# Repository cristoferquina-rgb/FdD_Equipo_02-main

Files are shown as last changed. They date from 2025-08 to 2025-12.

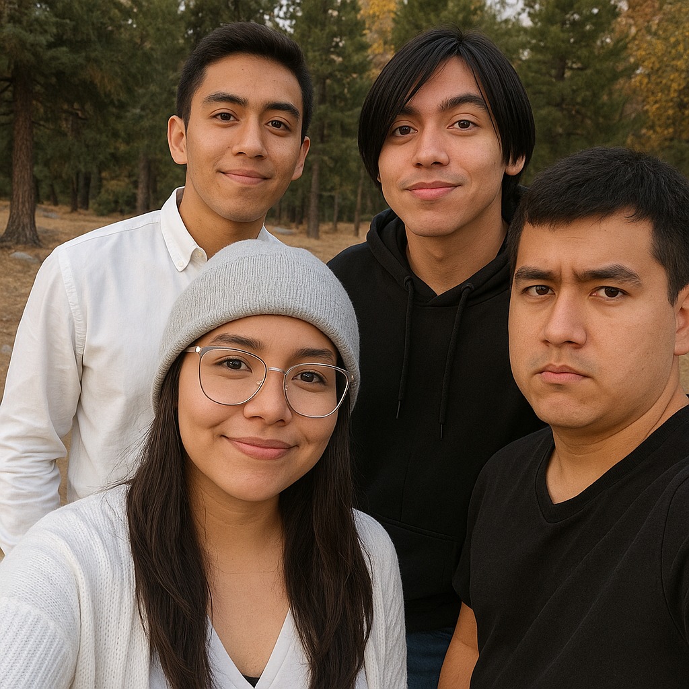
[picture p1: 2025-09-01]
Recursos/Imágenes/equipo.png

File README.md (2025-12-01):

# Equipo 02 - Fundamentos de Diseño 2025-2  
### Carrera de Ingeniería Informática / Industrial  
**Universidad Peruana Cayetano Heredia**



## 📑 Índice

1. [📘 Presentación del Equipo](#presentación-del-equipo)
2. [⭐ ODS Prioritario](#ods-prioritario)
3. [📸 Fotografía del Equipo](#fotografía-del-equipo)
4. [👥 Integrantes del Equipo](#integrantes-del-equipo)
5. [📝 Problemática en el Perú](#problemática-en-el-perú)
6. [💡 Propuesta de Solución – SmartVent](#propuesta-de-solución--smartvent)
7. [⚙️ Funciones del Sistema](#funciones-del-sistema)
8. [📦 Módulos del Proyecto](#módulos-del-proyecto)
    - [🔌 Módulo Electrónico](#módulo-electrónico)
    - [🛠️ Módulo Mecánico](#módulo-mecánico)
    - [💻 Módulo de Software](#módulo-de-software)
9. [📋 Componentes Utilizados](#componentes-utilizados)
10. [✨ Conclusiones y Trabajo Futuro](#conclusiones-y-trabajo-futuro)

## 📘 Presentación del Equipo

Somos el Equipo 02 del curso Fundamentos de Diseño 2025-2, conformado por estudiantes comprometidos con el desarrollo de soluciones innovadoras con impacto social, tecnológico y ambiental.

Nuestro trabajo se alinea con los Objetivos de Desarrollo Sostenible (ODS), especialmente los relacionados con ciudades sostenibles y resilientes.

## ⭐ ODS Prioritario

**ODS 11 – Ciudades y comunidades sostenibles**
**ODS 3 – Salud y Bienestar**

Nuestro prototipo se alinea con los ODS 3 (Salud y Bienestar) y ODS 11 (Ciudades Sostenibles), impulsando el bienestar y la sostenibilidad en el hogar. 

## 📸 Fotografía del Equipo  
<p align="center">

 <br>
  <em>Figura 1. Fotografía del equipo 2</em>
</p>

## 👥 Integrantes del Equipo  

| Foto | Nombre | Rol | Intereses |
|---|---|-----|---|
|  | **Idania Channara Parhuay Meza** | Líder del equipo | Innovación social, sostenibilidad |
|  | **Eber Pauccara Huancara** | Diseñador/a | Diseño de prototipos, creatividad aplicada |
|  | **Cristofer Andherson Quina Pumahuillca** | Encargado/a de documentación | Comunicación científica, redacción técnica |
|| **Sebastian Calderon Junes** | Programador/a - Modelador/a | Programación, análisis de datos, simulación |

## 📝Problemática en el Perú

En el Perú, la ventilación en viviendas, oficinas y colegios es ineficiente. Muchos espacios permanecen cerrados durante horas, lo que provoca acumulación de gases, humedad y temperaturas elevadas. Esto afecta la salud, la seguridad y el confort de los habitantes.

Además, los incendios urbanos representan un riesgo creciente. La inhalación de humo y gases tóxicos es una de las principales causas de muertes en siniestros domésticos. Muchas ventanas no cuentan con mecanismos de apertura rápida ni sistemas inteligentes que respondan automáticamente ante fugas de gas o humo.

Esta realidad evidencia la necesidad de un sistema retrofit, compacto, adaptable y seguro, capaz de mejorar la ventilación, detectar peligros y actuar sin intervención humana.

<p align="center">


## Propuesta de Solución – SmartVent

SmartVent es un módulo retrofit inteligente que integra sensores ambientales, un mecanismo motorizado de apertura y un sistema de comunicación para emergencias.
Permite ventilar de forma automática ante niveles peligrosos de gas o temperatura.

El sistema analiza continuamente el ambiente interior y responde mediante apertura, activación de alarmas y envío de alertas remotas. Su diseño es compacto, adaptable a marcos existentes y pensado para funcionar sin interrumpir la vida cotidiana.

<p align="center">


## Funciones del Sistema

🔹Función principal

- Integrar sensores de gases, temperatura y humedad en una ventana retrofit.
- Detectar fugas, cambios bruscos de temperatura y niveles críticos que comprometan la salud.
- Accionar automáticamente el mecanismo de apertura para ventilar.

🔹 Funciones secundarias

- Enviar alertas locales y remotas.
- Reconocer la calidad del aire y abrirse automáticamente si está contaminado.
- Activar apertura en situaciones de emergencia.

🔹 Funciones de control

- Procesar información en tiempo real con retroalimentación inmediata al usuario.

🔹 Funciones mecánicas

- Lograr movimiento estable mediante engranaje móvil.
- Permitir aperturas graduales.

🔹 Funciones de seguridad

- Detectar humo, gases y partículas tóxicas.
- Permitir apertura manual en caso necesario.

## Módulos del Proyecto

### 🔌Módulo Electrónico

- Incluye sensores de gases, temperatura, humedad y partículas.
- Cuenta con señales de entrada como: encendido, inicio, parada y lecturas de sensores.
- Cuenta con señales de salida como: estado, emergencia, fin de proceso y control de actuadores.
- Funciona conectado a la red eléctrica.
- El hardware incluye mecanismos que abren la ventana.

<p align="center">


### 🛠️Módulo Mecánico

- El módulo es compacto y adaptable a marcos existentes.
- Su cinemática garantiza un movimiento estable del engranaje y del sistema de apertura.
- El motor debe superar peso, fricción y presión del viento, con margen de seguridad.
- La estructura está diseñada según normas de seguridad contra incendios y calidad del aire.
- Incluye mecanismo de desbloqueo manual para emergencias.
- Está construido para cumplir criterios de ergonomía: suave, silencioso y fácil de usar para cualquier persona.
  
<p align="center">


### 💻Módulo de Software

- Controla sensores, alarmas, extractor y actuadores según el algoritmo.
- Ofrece una aplicación móvil con alertas e historial de calidad del aire.
- Cuenta con dashboard en tiempo real.
- El firmware administra adquisición de datos y control del actuador.
- Gestiona los modos de operación del sistema.

<p align="center">


## 📋Componentes Utilizados

A continuación se presenta un cuadro organizado para completar los componentes empleados en el proyecto, clasificados según su función dentro del sistema.

### 🔌Componentes Electrónicos

| Componente | Cantidad | Función | Exigencia Asociada |
|---|---|---|---|
| Sensor de gas (MQ-x) |1 | Detecta fugas de GLP y gases inflamables | Detectar fugas de gases dentro del ambiente |
| Sensor de temperatura y humedad (DHT/HTU21D) | 1 | Mide condiciones internas del ambiente | Propiedades físicas y químicas: temperatura y humedad |
| Microcontrolador (ESP32)| 1 | Procesamiento, control y comunicación | Centro del sistema: programa autónomo |
| Motor DC 12V 300 RPM | 1 | Acciona la apertura/cierre del sistema mecánico | Superar peso, fricción y presión del viento |
| Driver de motor | 1 | Control del motor mediante el microcontrolador | Control de salidas y actuadores |
| Fuente 12V / regulador | 1 | Alimentación del sistema con protecciones | Alimentación segura y estable |
| Alarma sonora (buzzer) | 1 | Aviso local de emergencias | Señales de emergencia |
| Indicador LED | 1 | Estado del sistema y alertas visuales | Señales luminosas del proceso |

---

### 🛠️Componentes Mecánicos

| Componente | Cantidad | Función | Exigencia Asociada |
|---|---|---|---|
| Engranaje principal | 1 | Transmitir movimiento al sistema de apertura | Cinemática estable del engranaje |
| Barra móvil / brazo mecánico | 1 | Efectuar el movimiento de apertura | Transmisión directa del motor |
| Estructura de soporte | 1 | Montaje seguro sobre la ventana | Instalación rápida y segura |
| Soportes y anclajes | 3 | Estabilidad del módulo | Robustez y resistencia |

---

### 💻Componentes de Software

| Elemento | Función | Exigencia Asociada |
|---|---|---|
| Firmware del microcontrolador | Control de sensores, motor y lógica | Gestión del proceso en tres modos |
| Aplicación móvil / Dashboard | Alertas, datos en tiempo real e historial | Comunicación con el usuario |
| Protocolo IoT (WiFi/Bluetooth) | Envío de notificaciones y monitoreo | Comunicación remota del sistema |

---

## ✨Conclusiones y Trabajo Futuro

SmartVent cumple todas las exigencias técnicas: control, seguridad, ergonomía, energía, señales, mecánica, software e instalación.

El sistema es seguro, silencioso, resistente y accesible.

La modularidad permite mantenimiento sencillo y reemplazo de piezas.

Futuras mejoras pueden incluir:

- Panel solar integrado,

- Más sensores,

- Integración con domótica,

- Versión industrial.

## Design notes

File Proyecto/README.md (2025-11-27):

# 📁 Proyectos – Organización General de Módulos

La carpeta Proyectos contiene los tres módulos principales desarrollados durante el proyecto integrador. Cada módulo aborda una parte esencial del sistema: la electrónica, la mecánica y el software.
A continuación se presenta una descripción general de cada uno.

## 🔌 1. Módulo Electrónico

Carpeta: [Proyectos/Modulo_Electronico](https://github.com/cristoferquina-rgb/FdD_Equipo_02-main/tree/main/Proyecto/M%C3%B3duloElectr%C3%B3nico)

Este módulo reúne todo el diseño y desarrollo del sistema electrónico, desde el esquemático hasta la placa PCB final.

Incluye:

● Diseño del circuito en EasyEDA

● Diseño de PCB (enrutado, capas, footprints)

## 🛠️ 2. Módulo Mecánico

Carpeta: [Proyectos/Modulo_Mecánico](https://github.com/cristoferquina-rgb/FdD_Equipo_02-main/tree/main/Proyecto/M%C3%B3duloMec%C3%A1nico)

En este módulo se encuentran todas las piezas y documentos relacionados al diseño físico del sistema.

Incluye:

● Certificados de Onshape

● Modelado 3D completo del ensamblaje

● Archivos .stl listos para impresión 3D

● Piezas como: caja, tapa, engranajes, soportes, correa, etc.

## 💻 3. Módulo de Software

Carpeta: [Proyectos/Modulo_Software](https://github.com/cristoferquina-rgb/FdD_Equipo_02-main/tree/main/Proyecto/M%C3%B3duloSoftware)

Este módulo contiene el código y la lógica del sistema digital que controla el proyecto.

Incluye:

● Programación del microcontrolador (Arduino, ESP32, etc.)

● Funciones de control y automatización

● Lectura de sensores y manejo de actuadores

● Algoritmos, librerías utilizadas y pruebas

● Documentación del flujo del software

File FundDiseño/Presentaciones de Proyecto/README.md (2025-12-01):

# PÓSTER

POSTER FDD

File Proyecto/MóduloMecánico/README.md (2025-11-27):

# 🛠️ Módulo Mecánico – Modelado 3D en Onshape

Esta sección presenta el desarrollo mecánico del proyecto, desde la validación del modelado en Onshape hasta la generación de las piezas finales exportadas en formato .stl listas para imprimir.

--- 

## ✔️ 1. Certificados de Onshape

Antes de iniciar el modelado, se completaron los módulos obligatorios de capacitación en Onshape, garantizando el uso correcto de herramientas de bocetado, ensamblaje y modelado 3D.

Puedes ver el certificado aquí: [Certificados Onshape](https://github.com/cristoferquina-rgb/FdD_Equipo_02-main/blob/main/Proyecto/M%C3%B3duloMec%C3%A1nico/Certificados%20Onshape.pdf)

## ✔️ 2. Modelado 3D del Sistema

Las piezas del proyecto fueron diseñadas completamente en Onshape, considerando:

● Dimensiones ajustadas al prototipo.

● Ensamblaje funcional entre componentes.

● Compatibilidad con impresión 3D.

● Tolerancias adecuadas para movimiento y acople.

● El modelado incluye: caja, tapa, engranajes, soportes y la correa del mecanismo.

## ✔️ 3. Archivos STL listos para impresión

Los siguientes archivos .stl corresponden a cada una de las piezas diseñadas.
Están listos para ser abiertos en Cura, PrusaSlicer u otro software de impresión 3D.

📦 Piezas del ensamblaje:

● [Caja](https://github.com/cristoferquina-rgb/FdD_Equipo_02-main/blob/main/Proyecto/M%C3%B3duloMec%C3%A1nico/Caja.stl)

● [Tapa]( https://github.com/cristoferquina-rgb/FdD_Equipo_02-main/blob/main/Proyecto/M%C3%B3duloMec%C3%A1nico/tapa.stl)

● [Soporte]( https://github.com/cristoferquina-rgb/FdD_Equipo_02-main/blob/main/Proyecto/M%C3%B3duloMec%C3%A1nico/soporte.stl)

● [Soporte del motor]( https://github.com/cristoferquina-rgb/FdD_Equipo_02-main/blob/main/Proyecto/M%C3%B3duloMec%C3%A1nico/Soporte%20del%20motor.stl)

● [Correa de ventana]( https://github.com/cristoferquina-rgb/FdD_Equipo_02-main/blob/main/Proyecto/M%C3%B3duloMec%C3%A1nico/Correa%20de%20ventana.stl)

● [Engranaje]( https://github.com/cristoferquina-rgb/FdD_Equipo_02-main/blob/main/Proyecto/M%C3%B3duloMec%C3%A1nico/Engranaje.stl)

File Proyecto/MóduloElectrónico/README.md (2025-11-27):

# 🔌 MÓDULO ELECTRÓNICO –  EasyEDA & PCB

Este apartado reúne todo el proceso de diseño electrónico realizado para el proyecto, desde el esquema del circuito hasta la fabricación de la tarjeta PCB.

## ✔️ 1. Diseño del Circuito en EasyEDA

Se desarrolló el esquemático electrónico utilizando EasyEDA, donde se definieron todos los componentes, sus conexiones y la lógica del circuito.
Incluye:

● Selección y colocación de componentes electrónicos.

● Conexión del circuito mediante señales (nets).

● Organización del diagrama con etiquetas y bloques para una lectura clara.

esquema final grupo2_page-0001

---

## ✔️ 2. Diseño del Circuito en EasyEDA (Todos los componentes con fotoprint)
Captura de pantalla 2025-11-24 121837

---

## ✔️ 3. Generación del PCB

A partir del esquemático final se creó la tarjeta de circuito impreso (PCB), también en EasyEDA.

El proceso incluyó:

● Asignación de footprints adecuados para cada componente.

● Ruteo manual y/o automático de pistas.

● Definición de capas (TOP/BOTTOM).

● Ubicación óptima de componentes para minimizar interferencias y facilitar la fabricación.

Captura de pantalla 2025-11-24 121418

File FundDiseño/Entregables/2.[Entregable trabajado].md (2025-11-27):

# LISTA DE EXIGENCIA  
**Páginas:** 6  
**Proyecto:** SmartVent  
**Fecha:** 30/09/25  
**Cliente:** Universidad Peruana Cayetano Heredia  
**Elaborado por:** I.P, E.P, S.C, C.Q  

---

## 📌 Lista de exigencias

| Fecha | Deseo o Exigencia | Tipo | Descripción | Responsable |
|---|---|---|---|---|
| 23/09/25 | E | Función principal |**Función principal:**<br> ● Integrar sensores de gases y temperatura en ventanas retrofit para accionar mecanismo de apertura. Detectar fugas de gases, cambios bruscos de temperatura y niveles de humedad que puedan afectar la salud y seguridad de los habitantes, y abrirse automáticamente para ventilar el espacio.<br> **Función secundaria:**<br>● Enviar alertas locales de mensajería mediante whatsapp y remotas en situaciones de emergencia, contribuyendo a la seguridad del entorno.<br>● Reconocer la calidad del aire exterior y en caso de que esté contaminado, cerrarse automáticamente para evitar que entre al interior. |E.P, S.C | 
| 23/09/25 | E | Geometría | El módulo retrofit debe ser compacto y adaptable a marcos existentes, con dimensiones de referencia que permitan una instalación segura sin afectar la ergonomía del usuario ni la compatibilidad con marcos estándar. |E.P, S.C | 
| 23/09/25 | E | Cinemática | El mecanismo de apertura y cierre debe garantizar un movimiento estable y seguro del engranaje móvil. Para ello se emplea un sistema motor con transmisión mecánica que permite aperturas parcial y total en situaciones de emergencia, manteniendo la integridad estructural de la ventana. | I.P, E.P |
| 23/09/25 | E | Fuerzas | El actuador debe superar el peso de la hoja y las resistencias externas como fricción y presión del viento, considerando un margen de seguridad adecuado. Además, debe prevenir desalineaciones y contar con mecanismos de detección de obstáculos para asegurar un funcionamiento confiable. | S.C, C.Q |
| 23/09/25 | E | Energía | El sistema será alimentado de la red eléctrica convencional, incorporando una fuente de conversión adecuada para el motor y sensores Además, debe incluir protecciones eléctricas básicas y gestión en modo reposo para optimizar el consumo.| E.P, S.C |
| 23/09/25 | E | Materia | ● Flujo material y transporte: Aire interior y exterior (intercambio controlado).<br>● Propiedades físicas y químicas: Concentración de gas licuado de petróleo(GLP) y derivados de ellos, humedad relativa y temperatura.<br>● Productos de entrada y salida: Entrada de aire limpio; salida de aire contaminado y  gases tóxicos presentes en el medio.<br>● Materiales adicionales: Marcos anticorrosivos, vidrio, motores, sensores.<br>● Materiales normativos: Cumplimiento de normas de seguridad contra incendios y calidad del aire (referencia a OMS e INDECI).| I.P, E.P, S.C, C.Q |
| 23/09/25 | E | Señales de información |El sistema contará con las siguientes señales de entrada y salida:<br>**Entrada:** <br>●Señal de encendido: Sirve para activar los componentes eléctricos y electrónicos que conforman la máquina.<br>● Señal de inicio: Esta señal pone en marcha el funcionamiento conjunto del proceso.<br>● Señal de parada: Permite detener el proceso en cualquier etapa de su funcionamiento.<br>● Señales de sensores: Lecturas de sensores ambientales( sensor de gases, sensor de temperatura y humedad).<br>**Salida:** <br>stand-by, estado, emergencia, fin de proceso, control de actuadores. | I.P, E.P, S.C, C.Q |
| 23/09/25 | E | Control | Algoritmo que procesa datos, opera en modo normal/parcial/emergencia, supervisión en tiempo real. | I.P, E.P |
| 23/09/25 | E | Electrónico (Hardware) | Incluye microcontrolador, sensores inteligentes, mecanismos de apertura/cierre, batería de respaldo y opción de energía solar. | S.C, C.Q |
| 23/09/25 | E | Software | App móvil, dashboard, firmware de control, notificaciones IoT. | S.C, E.P |
| 23/09/25 | E | Comunicaciones | Conexión inalámbrica estable y segura, comunicación bidireccional. | I.P |
| 23/09/25 | E | Seguridad | Detecta humo, gases y partículas; abre ventanas y activa alarmas; funciona incluso con corte eléctrico por batería. | I.P, E.P |
| 23/09/25 | E | Ergonomía | Diseño para todo tipo de usuario, suave y silencioso; app intuitiva. | S.C, C.Q |
| 23/09/25 | E | Fabricación | Materiales resistentes; diseño modular; combinación de talleres locales y proveedores electrónicos. | E.P, I.P, S.C, C.Q |
| 23/09/25 | E | Control de calidad | Pruebas de sensores, mecanismos y validación en entornos reales. | I.P, E.P |
| 23/09/25 | E | Montaje | Instalación rápida y adaptable, con manual intuitivo. | S.C, C.Q |
| 23/09/25 | E | Transporte | Producto compacto, ≤ 2.5 kg, embalado contra golpes y humedad. | E.P |
| 23/09/25 | D | Uso | Motor DC 12V 300 RPM (30 kg fuerza), operación silenciosa, desbloqueo manual en emergencias. | I.P |
| 23/09/25 | E | Mantenimiento | Limpieza de sensores y revisión de batería cada 6 meses; diagnósticos automáticos. | S.C, E.P |
| 23/09/25 | E | Costos | Componentes accesibles, bajo costo de producción, amortización en 2–3 años. | I.P, E.P |
| 23/09/25 | E | Plazos | Desarrollo estimado: 2–3 meses desde diseño hasta prototipo. | C.Q, I.P |

---

# PLAN DE TRABAJO
Captura de pantalla 2025-11-24 123751

---

# CAJA NEGRA
 
caja negra

---

# ESTRUCTURA DE FUNCIONES 

ESTRUCTURADE FUNCIONES

---

# MATRIZ MORFOLÓGICA







---

# MATRIZ PUGH

Matriz pugh_page-0001

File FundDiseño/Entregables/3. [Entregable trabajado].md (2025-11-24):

# BOCETOS 

bocetos_grupo2_page-0001
bocetos_grupo2_page-0002
bocetos_grupo2_page-0003

----

# PLANOS 2D

## Planos de la caja
Part 1 Drawing 1_page-0001

## Planos de la tapa
Planos de la tapa_page-0001

## Planos del soporte
Planos del soporte_page-0001

## Planos del soporte de motor
Planos de soporte del motor_page-0001

## Planos de correa de ventana 
Planos de la correa de ventana_pages-to-jpg-0001

## Planos del engranaje
Planos del engranaje_page-0001

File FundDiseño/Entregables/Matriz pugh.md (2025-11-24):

# MATRIZ PUGH

Matriz pugh_page-0001

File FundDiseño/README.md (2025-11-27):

# 📘 Repositorio 

Este repositorio organiza los archivos, entregables y recursos desarrollados durante el proyecto.
A continuación se describe cada carpeta y lo que contiene.

## 📂 1. Entregables

Carpeta: [Entregables](https://github.com/cristoferquina-rgb/FdD_Equipo_02-main/tree/main/FundDise%C3%B1o/Entregables)

Esta sección reúne los documentos formales entregados durante el avance del proyecto.
Incluye:

✔️ Entregable 1: Lista de exigencias, plan de trabajo, caja negra, estructura de funciones, matriz morfológica, matriz Pugh .

✔️ Entregable 2: Bocetos 2D, planos técnicos del modelado 3D.

✔️ Documentos PDF, imágenes y archivos .md asociados a cada entrega.

## 🎤 2. Presentaciones de Proyecto

Carpeta: [Presentaciones de Proyecto](https://github.com/cristoferquina-rgb/FdD_Equipo_02-main/tree/main/FundDise%C3%B1o/Presentaciones%20de%20Proyecto)

Aquí se agrupan todas las presentaciones realizadas para el proceso del proyecto, desde avances hasta la presentación final.

Incluye:

✔️ Avance del proyecto

✔️ Póster 

✔️ Presentación final

✔️ Imágenes, archivos, información usados en las diapositivas

## 📝 3. Talleres

Carpeta: [Talleres](https://github.com/cristoferquina-rgb/FdD_Equipo_02-main/tree/main/FundDise%C3%B1o/Talleres)

Contiene los talleres desarrollados durante el transcurso del curso, el cual nos han ayudado a poder reforzar conocimientos para poder realizar este proyecto.

Esta carpeta muestra la evolución del aprendizaje y la aplicación práctica de cada tema.

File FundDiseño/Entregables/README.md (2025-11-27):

# PROYECTO -  ENTREGABLES DEL CICLO

Este repositorio contiene los entregables desarrollados a lo largo del proyecto. Cada sección incluye los documentos y recursos utilizados durante el proceso de diseño, análisis y modelado.

---
## 🧩 Entregable 2 — Desarrollo Conceptual y Analítico

Este entregable reúne todo el proceso inicial de análisis del problema, definición del producto y evaluación de alternativas.

[Entregable_2](https://github.com/cristoferquina-rgb/FdD_Equipo_02-main/blob/main/FundDise%C3%B1o/Entregables/2.%5BEntregable%20trabajado%5D.md)

✔️ **1. Lista de Exigencias**

Conjunto de requisitos funcionales y no funcionales que el producto debe cumplir. Sirve como base para evaluar y validar las propuestas generadas. 

✔️ **2. Plan de Trabajo**

Cronograma y organización del equipo, donde se especifican tareas, tiempos estimados, responsables y etapas del proyecto.

✔️ **3. Caja Negra**

Descripción general del sistema, mostrando entradas, procesos internos y salidas del producto. Permite visualizar la función principal sin entrar en detalles técnicos.

✔️ **4. Estructura de Funciones**

Descomposición jerárquica de las funciones principales y secundarias del sistema. Ayuda a comprender cómo se organiza el producto a nivel funcional.

✔️ **5. Matriz Morfológica**

Tabla donde se proponen diferentes soluciones o alternativas para cada función del producto. Permite explorar diversas combinaciones.

✔️ **6. Matriz Pugh**

Método de selección de alternativas donde se comparan las opciones generadas con un patrón de referencia, permitiendo seleccionar la mejor propuesta.

---

## 🛠️ Entregable 3 — Diseño y Desarrollo del Producto

Este entregable recopila el trabajo gráfico y técnico del diseño final del producto.

[Entregable_3](https://github.com/cristoferquina-rgb/FdD_Equipo_02-main/blob/main/FundDise%C3%B1o/Entregables/3.%20%5BEntregable%20trabajado%5D.md)

✔️ **1. Bocetos 2D**

Ilustraciones iniciales del diseño en dos dimensiones. Permiten visualizar la forma, proporciones y posibles configuraciones antes del modelado digital.

✔️ **2. Planos 2D (Onshape)**

Modelos realizados en Onshape, incluyendo los planos técnicos del modelo final que fue enviado a imprimir, con medidas, cortes, vistas y detalles necesarios para su fabricación.

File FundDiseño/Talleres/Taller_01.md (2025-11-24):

# Zotero

Eber:

El artículo de Bian y Huang (2024) presenta una innovadora metodología para monitorear en tiempo real y a largo plazo la turbidez del agua costera mediante una boya oceánica equipada con un perfilador acústico Doppler (ADCP). A través de la correlación entre las intensidades de eco acústico del ADCP y mediciones obtenidas con un turbidímetro óptico, los autores lograron calibrar y estimar perfiles continuos de turbidez en diferentes profundidades. El estudio, realizado en la costa de Taiwán, demostró que las mareas y corrientes son los principales factores que influyen en la turbidez, mientras que el oleaje tiene un impacto limitado a mayor profundidad. Esta técnica permite un monitoreo confiable y sin sensores ópticos sumergidos, ofreciendo una solución eficiente y segura para el estudio del transporte de sedimentos en ambientes marinos (1).

Idania:

Cabanillas‑Chirinos et al. (2024) evaluaron la contaminación microbiológica y la resistencia antimicrobiana en agua de mar de tres playas populares en Trujillo, Perú Salaverry, Las Delicias y Huanchaco durante octubre y noviembre de 2023. Los resultados mostraron que Salaverry presentaba buena calidad microbiológica, mientras que Las Delicias y Huanchaco evidenciaron contaminación significativa, con Escherichia coli siendo la bacteria más frecuentemente aislada. Además, se identificó resistencia a antimicrobianos comunes como ampicilina y ciprofloxacino, lo cual revela que los vertidos de aguas residuales costeras representan un riesgo latente para los bañistas durante la temporada festival (2).

Sebastian

El estudio de Yoshizawa y colaboradores evaluó cómo el agua de mar y sus principales componentes influyen en la dermatitis de contacto irritativa experimental provocada por lauril sulfato de sodio (SLS). Los resultados mostraron que tanto el agua de mar como las soluciones de NaCl y KCl redujeron significativamente el daño en la función barrera de la piel (medido por la pérdida transepidérmica de agua) en comparación con el agua desionizada. Además, NaCl ayudó a prevenir la sequedad cutánea gracias a su efecto higroscópico. En conclusión, el agua de mar y ciertos minerales podrían contribuir a preservar la barrera cutánea y ser útiles como terapia complementaria en dermatitis crónica(3).

Quina:

Los monitoreos realizados en Pacasmayo, Malabrigo, Huanchaco y Salaverry entre 2019 y 2020 evidenciaron que la contaminación marina está asociada a descargas de materia orgánica y fecal, lo que ha generado deterioro en la calidad del agua, los sedimentos y las comunidades biológicas de la zona(4)

Referencias bibliográficas:

1.	Xu G, Shen W, Wang X. Applications of Wireless Sensor Networks in Marine Environment Monitoring: A Survey. Sensors [Internet]. 11 de septiembre de 2014 [citado 1 de septiembre de 2025];14(9):16932-54. Disponible en: https://www.mdpi.com/1424-8220/14/9/16932 
2.	Cabanillas-Chirinos L, De La Cruz-Noriega M, Soto Deza N, Diaz Del Aguila K, Terrones Rodríguez N, García Cedron D, et al. Microbiological contamination and antimicrobial resistance in seawater samples from three beaches in Trujillo, Peru. Proc 22nd LACCEI Int Multi-Conf Eng Educ Technol LACCEI 2024 “Sustainable Eng Diverse Equitable Incl Future Serv Educ Res Ind Soc 50” [Internet]. 2024 [citado 1 de septiembre de 2025]; Disponible en: https://laccei.org/LACCEI2024-CostaRica/meta/FP1935.html 
3.	Yoshizawa Y, Tanojo H, Kim SJ, Maibach HI. Sea water or its components alter experimental irritant dermatitis in man. Skin Res Technol [Internet]. febrero de 2001 [citado 1 de septiembre de 2025];7(1):36-9. Disponible en: https://onlinelibrary.wiley.com/doi/10.1034/j.1600-0846.2001.007001036.x 
4.	Castillo R, Mudarra A, Moreyra O. Víctor Rebaza Castillo1 Santos Alfaro Mudarra1 Rita Orozco Moreyra2. 2024;51(2).

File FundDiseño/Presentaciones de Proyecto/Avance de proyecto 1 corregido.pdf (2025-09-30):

Universidad Peruana Cayetano Heredia

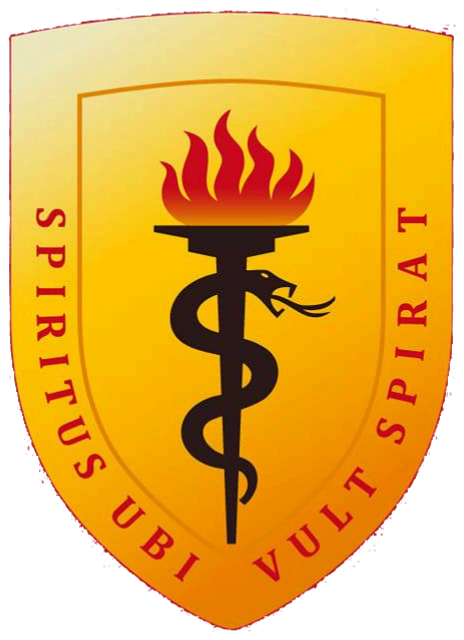
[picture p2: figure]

CARRERAS DE INGENIERÍA - FUNDAMENTOS DE DISEÑO 2025 - II

Grupo 2

Integrantes

Nombres | Apellidos | Código de estudiante
Cristofer Andherson | Quina Pumahuilca | 73332313
Eber David | Pauccara Huancara | 720453108
Idania Channara | Parhuay Meza | 60784588
Sebastian Alessandro | Calderon Junes | 60413613

### SmartVent: Análisis de Requisitos y Fundamentos para una

Ventana Inteligente Retrofit.

### 1. Introducción:

En Lima, la vida diaria se desarrolla en medio de dos riesgos silenciosos que

muchas veces pasamos por alto: el aire que respiramos en interiores y la constante

amenaza de los incendios. Pasamos gran parte del día en espacios cerrados como

casas, colegios u oficinas, y aunque pensemos que son lugares seguros, la realidad es

distinta. El aire se va cargando de dióxido de carbono (CO₂) y humedad, lo que reduce

la concentración y el bienestar. Además, la contaminación exterior no ayuda: las

partículas finas (PM2.5) en la ciudad superan hasta tres veces los niveles

recomendados por la Organización Mundial de la Salud, lo que significa que abrir una

ventana para “ventilar” puede ser tan dañino como no hacerlo (IQAir, 2024).

Por otro lado, los incendios urbanos siguen siendo una amenaza constante. La

mayoría de muertes en estos siniestros no se debe a las llamas, sino al humo y los

gases tóxicos que llenan rápidamente los ambientes, impidiendo ver, respirar y

reaccionar a tiempo (NFPA, 2019; INDECI, 2022). Esta situación se vuelve aún más

dura en distritos con pocos recursos, donde las familias no cuentan con sistemas de

ventilación o de seguridad adecuados, y donde niños, adultos mayores y personas con

movilidad reducida son los más vulnerables.

Ante este panorama, surge la necesidad de pensar en soluciones prácticas y

accesibles que realmente marquen la diferencia. De ahí nace SmartVent: Ventana

Inteligente Retrofit, una propuesta que busca transformar cualquier ventana común en una aliada para el cuidado de la salud y la seguridad. Gracias a sensores y sistemas

automáticos, la idea es que el dispositivo regule la ventilación cuando la calidad del

aire no sea buena y que, en caso de incendio, facilite la evacuación y reduzca la

exposición al humo.

Este informe presenta los fundamentos, el análisis de requisitos y las

referencias necesarias para darle forma a SmartVent, con el objetivo de demostrar

cómo la tecnología puede adaptarse a la vida diaria de las personas y ofrecer

soluciones reales a problemas tan urgentes como respirar aire limpio y estar

protegidos en caso de emergencia.

### 2. Objetivo del informe:

El análisis de requisitos y fundamentos para el desarrollo de SmartVent, una

ventana inteligente de tipo retrofit, parte de la necesidad de identificar referencias de

productos existentes que presenten similitudes y permitan establecer un punto de

inicio sólido para su diseño. En el mercado actual se pueden encontrar soluciones

como sistemas de ventilación inteligente para el hogar, ventanas automatizadas y kits

de domótica que integran sensores de temperatura, humedad y calidad del aire. Estos

productos ofrecen un marco de comparación valioso, ya que comparten el objetivo de

optimizar la ventilación, mejorar el confort térmico y garantizar una mayor eficiencia

energética en los espacios habitados. Por ejemplo, compañías dedicadas a la domótica

han desarrollado persianas y ventanas con apertura automática, gestionadas mediante

aplicaciones móviles o asistentes virtuales, lo cual demuestra la creciente tendencia

hacia el control remoto y la personalización del ambiente interior. Asimismo, algunos

dispositivos independientes de monitoreo ambiental proporcionan información en

tiempo real sobre la calidad del aire, mostrando cómo la combinación de hardware y software orientado a la salud y la sostenibilidad representa un valor agregado

altamente demandado por los usuarios.

En este contexto, SmartVent se diferencia al plantear un enfoque retrofit, es

decir, una solución que no exige reemplazar completamente la ventana existente, sino

adaptar un módulo tecnológico a estructuras ya instaladas. Este enfoque reduce

costos, facilita la adopción por parte de los usuarios y se alinea con la filosofía de

sostenibilidad al prolongar la vida útil de las infraestructuras actuales. Para sustentar

esta propuesta, es necesario considerar requisitos técnicos como la compatibilidad con

diferentes tipos de marcos, la autonomía energética mediante paneles solares de bajo

consumo, la conectividad inalámbrica para su integración en sistemas de hogar

inteligente y la facilidad de instalación sin necesidad de mano de obra especializada.

Igualmente, deben contemplarse aspectos normativos relacionados con la seguridad,

la aislación acústica y la eficiencia energética, de modo que el producto final cumpla

con estándares de calidad internacional. En síntesis, el análisis comparativo de

productos similares permite no solo establecer las bases tecnológicas para SmartVent,

sino también identificar los atributos diferenciadores que lo convierten en una

alternativa innovadora, accesible y sostenible en el ámbito de las ventanas

inteligentes.

### 3. Revisión de la Literatura:

### 3.1. Artículo 1:

❖ Titulo del articulo: Enhancing gas leak detection with IoT technology: An

innovative approach

❖ Autores: Babu, T., Nair, R. R., Kishore, S., & Vineeth, M.

❖ Fecha de publicación: 2024

❖ Revista: Procedia Computer Science, 235, 961–969.

El estudio de Babu, Nair, Kishore y Vineeth (2024) aborda un problema

crítico: las fugas de gas en entornos domésticos, industriales y comerciales.

Estas fugas representan una amenaza seria para la seguridad, ya que pueden

provocar incendios, explosiones, intoxicaciones y daños materiales. Los

métodos tradicionales de detección, como alarmas básicas o revisiones

manuales, son limitados porque carecen de monitoreo en tiempo real y de un

sistema de alertas que llegue de manera rápida a los usuarios o a las

autoridades.

Para superar estas limitaciones, los autores proponen un sistema inteligente

de detección de fugas de gas basado en Internet de las Cosas (IoT). La

arquitectura del sistema combina:

- Sensores MQ2: capaces de detectar múltiples gases peligrosos

(metano, propano, monóxido de carbono e hidrógeno), lo que ofrece

una cobertura más amplia frente a distintas amenazas.

- Módulo NodeMCU con conectividad Wi-Fi: funciona como unidad

de control, procesando los datos recibidos de los sensores en tiempo

real y enviándolos a la nube o a un servidor central.

- Plataforma de alertas: el sistema genera notificaciones inmediatas vía

SMS, correo electrónico o aplicaciones móviles/web, asegurando que

los usuarios reciban información crítica sin demora.

- Registro histórico y analítica de datos: además de la alerta

inmediata, el sistema guarda registros que permiten identificar patrones

de concentración de gases y evaluar la evolución de las condiciones

ambientales.

- Integración con sistemas de automatización: el sistema puede

vincularse con mecanismos de seguridad adicionales, como el cierre

automático de válvulas de gas, la activación de sistemas de ventilación

o la notificación directa a servicios de emergencia.

El proceso de funcionamiento incluye adquisición de datos, preprocesamiento

para eliminar ruido o errores, análisis en tiempo real con algoritmos de

detección de anomalías, y generación de alertas cuando se superan umbrales

críticos. Este flujo garantiza que cualquier fuga sea identificada de manera

temprana y que las acciones de respuesta se ejecuten rápidamente.

Los resultados obtenidos en las pruebas demostraron que el prototipo tiene alta

precisión en la detección y que las alertas se emiten en cuestión de segundos.

Esto se traduce en una reducción significativa de riesgos asociados con fugas

de gas, mejorando la protección de la vida humana, la infraestructura y el

medio ambiente.

En su conclusión, los autores destacan que el sistema no solo cumple con la

función de detección temprana, sino que también constituye un mecanismo de

prevención proactiva al integrarse con tecnologías de automatización y análisis de datos. Asimismo, señalan que, aunque todavía existen retos

técnicos relacionados con la calibración de sensores, la fiabilidad de la

comunicación y la precisión del análisis, la propuesta representa un avance

clave en el desarrollo de hogares e industrias más seguras mediante soluciones

IoT.

### 3.2. Artículo 2:

❖ Titulo del Articulo: Advancements in air quality monitoring: A systematic

review of IoT-enabled systems

❖ Autores: Soh, Z. H. C., Abdullah, S. A. C., Shafie, M. A., & Ibrahim, M. N.

❖ Fecha de publicación: 2024

❖ Revista: Environmental Monitoring and Assessment, 196(640).

Este artículo presenta una revisión sistemática de los principales avances en

sistemas de monitoreo de calidad del aire basados en Internet de las Cosas

(IoT), poniendo énfasis en cómo los desarrollos previos han sentado las bases

para soluciones actuales más eficientes, económicas y escalables. El tema es

relevante debido al incremento de contaminantes como PM2.5, PM10, NO₂,

CO y O₃, que generan problemas graves de salud pública y deterioro

ambiental.

1. Estudios previos revisados:

Los autores organizan los antecedentes en cuatro grandes ejes:

a. Sensores utilizados:

Muchos estudios previos emplearon sensores electroquímicos y ópticos

de bajo costo (ej. MQ series, SDS011, DHT11), que permitieron democratizar el monitoreo en comunidades con menos recursos. Sin

embargo, se detectaron problemas de precisión al compararlos con

estaciones de referencia, lo que obligó a implementar procesos de

calibración cruzada y algoritmos de corrección.

b. Plataformas de procesamiento y hardware:

Se revisaron experiencias con microcontroladores y placas de

desarrollo como Arduino, Raspberry Pi, ESP8266 y ESP32.

Estudios previos mostraron que estas plataformas son eficientes para

recolectar y transmitir datos ambientales en tiempo real, aunque su

capacidad de procesamiento es limitada frente a algoritmos complejos.

c. Conectividad y transmisión de datos

Los sistemas más tempranos dependían de Wi-Fi, lo que limitaba su

alcance a entornos urbanos con buena cobertura. Investigaciones más

recientes incorporan tecnologías de bajo consumo y largo alcance

como LoRaWAN y NB-IoT, lo que amplió la cobertura en zonas

rurales e industriales. Estos avances permitieron superar la

dependencia de redes locales, algo que los autores consideran un salto

clave en el desarrollo de sistemas más autónomos.

d. Gestión de datos y visualización
- Diversos trabajos implementaron plataformas en la nube (ThingSpeak,

Ubidots, Firebase) para almacenamiento y análisis.

- Los dashboards y aplicaciones móviles surgieron como herramientas

centrales para dar acceso a usuarios, comunidades y autoridades.

- Algunos estudios integraron alertas automáticas vía SMS, correo

electrónico o notificaciones push, mejorando la respuesta ante picos de

contaminación.

2. Incorporación de inteligencia artificial
- Varios proyectos iniciales se limitaron a la simple detección y

almacenamiento de datos.

- Estudios más recientes aplicaron machine learning para predecir

niveles de contaminantes, detectar anomalías y mejorar la precisión de

sensores de bajo costo.

- Los autores destacan que esta línea de investigación es aún incipiente,

pero con gran potencial de desarrollo.

3. Síntesis crítica de los antecedentes:

De la revisión, los autores concluyen que los estudios previos han demostrado

el valor del IoT en el monitoreo ambiental, pero también dejaron claros ciertos

vacíos y limitaciones:

- La mayoría de los sistemas carecen de protocolos estandarizados de

calibración y validación.

- Los problemas de precisión y confiabilidad de sensores de bajo costo

siguen siendo un desafío central.

- La seguridad y privacidad de los datos es un tema poco abordado en

los trabajos analizados.

- Muchos sistemas priorizan la recolección de datos, pero no se integran

con modelos predictivos ni con políticas públicas.

4. Aporte del artículo

El valor de esta revisión está en que sistematiza la información disponible y

señala una ruta clara: la combinación de sensores accesibles con big data e

inteligencia artificial, en sistemas escalables y seguros, capaces de integrarse a

estrategias urbanas de sostenibilidad y salud pública.

Los autores subrayan que el futuro del campo depende de soluciones híbridas

(sensores + IA + nube) que permitan no solo medir, sino también anticipar

escenarios de contaminación y actuar preventivamente.

### 3.3. Artículo 3:

❖ Titulo del Articulo: Smart Gas Leak Detection And Emergency Response

System Using Iot For Homes:

❖ Autores: Shah, A. S., Dinesh, A., Shah, A., Farooq, M., Maqsood, A., &

Khani, M. A. K. (2024)

❖ Fecha de publicación: 21 June 2024

❖ Revista: International Journal of Advance Soft Computing and Applications

(IJASCA), volumen 11(1), páginas 132–145, año 2019.

El artículo aborda la problemática de las fugas de gas domésticas (metano,

GLP y monóxido de carbono), que representan un riesgo severo de incendios,

explosiones y envenenamiento. Los detectores convencionales suelen limitarse

a emitir alarmas sonoras o luminosas, lo que exige la presencia de una persona

para actuar y, en muchos casos, no resulta suficiente para prevenir accidentes.

Con el fin de mejorar la seguridad, los autores desarrollan un sistema de

detección y respuesta inteligente basado en IoT. El diseño utiliza sensores

MQ-9 conectados a un microcontrolador NodeMCU, junto con un módulo

Wi-Fi, un servomotor, ventiladores de extracción y una válvula de gas. La

información se gestiona en tiempo real mediante una aplicación móvil

sincronizada con Firebase, lo que permite tanto la visualización de los datos

como el control remoto de los dispositivos.

El funcionamiento del sistema es el siguiente:

■ Monitoreo en tiempo real: El sensor MQ-9 mide continuamente la

concentración de gas en el ambiente.

- Procesamiento y decisión: Si la concentración supera el umbral

predefinido (900 ppm), el NodeMCU activa automáticamente las

medidas de seguridad.

- Medidas de prevención: Cierre de la válvula principal de gas,

encendido del extractor, apertura de ventanas y activación de alarmas

(buzzer/LED).

- Notificación inmediata: El sistema envía alertas al usuario mediante

la app móvil (notificaciones push) y a los servicios de emergencia a

través de SMS (usando la API de Twilio).

- Visualización y control: Desde la aplicación, el usuario puede

supervisar los niveles de gas, configurar umbrales y gestionar

manualmente los dispositivos de seguridad.

En las pruebas experimentales, el sistema demostró ser altamente sensible y

confiable. Detectó fugas rápidamente, activó las medidas preventivas de

manera automática y redujo la concentración de gas en pocos segundos.

Además, mantuvo la capacidad de operar en modo offline, sincronizando datos

en Firebase una vez restablecida la conexión.

Los autores concluyen que este sistema supera a los detectores tradicionales,

ya que no solo alerta al usuario, sino que también implementa acciones

preventivas de forma autónoma. Esto reduce significativamente el riesgo de

accidentes en entornos domésticos y pequeños negocios. Como línea futura,

sugieren incorporar inteligencia artificial y sensores más avanzados que

permitan distinguir entre diferentes gases y realizar ajustes automáticos en los

umbrales de seguridad.

En general, los tres artículos revisados nos muestran cómo la combinación de

sensores y sistemas IoT se está convirtiendo en una herramienta clave para mejorar la

calidad del aire interior y la seguridad en los hogares. El trabajo de Babu et al. (2024)

confirma que es posible usar sensores accesibles como el MQ2 para detectar gases

inflamables de forma práctica. Por otro lado, Soh et al. (2019) refuerza la importancia

de que estos sistemas cuenten con alertas inmediatas y control remoto, ya que eso

aumenta la seguridad del usuario. Finalmente, la revisión de Shah et al. (2024) nos da

una mirada más amplia, mostrando que aunque hay avances, todavía existen retos

importantes como la calibración de sensores y la falta de protocolos estandarizados.

En conjunto, los tres trabajos coinciden en que los sensores, la conectividad IoT y la

automatización son fundamentales, pero también dejan claro que hay limitaciones que

todavía no están resueltas. Esto respalda la propuesta de SmartVent, ya que justifica la

necesidad de un sistema que combine detección confiable, alertas oportunas y un

diseño retrofit que lo haga más accesible y útil frente a lo que ya existe en el mercado.

### 4. Patentes Referenciales:

4.1. Patente 1:
- Nombre de la patente: Household kitchen gas leakage intelligent window
- País de origen: China
- Fecha de patentado: 22 de diciembre de 2020
- Código: CN212201795U
- Enlace directo:

https://worldwide.espacenet.com/patent/search/family/073692329/publication/

CN212201795U?q=CN212201795U (https://worldwide.espacenet.com/patent/search/family/073692329/publication/CN212201795U?q=CN212201795U)

El modelo de utilidad denominado Household kitchen gas leakage intelligent

window consiste en una ventana inteligente destinada a reforzar la seguridad en

cocinas domésticas frente a posibles fugas de gas. La estructura principal está

conformada por un marco inteligente (1) de aproximadamente 1200 mm de ancho,

1000 mm de alto y 120 mm de grosor, que alberga en uno de sus laterales un

módulo de control (23) con dimensiones de 200 × 100 × 80 mm. Dicho módulo

integra una luz estroboscópica LED (4) de alta luminosidad, un sensor de gas

semiconductor (5) con capacidad de detección en el rango de 200–10 000 ppm, y

una alarma acústica (11) de nivel sonoro superior a 85 dB, diseñada para alertar

tanto al usuario como a los vecinos cercanos en caso de emergencia.

En el interior del marco se encuentra un soporte estructural (13) que fija un

servomotor (14) de 12 V y 30 W, el cual transmite movimiento a un primer eje

rotatorio (15) de Ø10 mm. Este eje acciona un sistema de polea motriz (16), correa

(17) y polea conducida (18), que a su vez impulsa un husillo roscado (8) de M12 ×

1.5 mm acoplado a una tuerca roscada (7) con bloque deslizante (6). Este

mecanismo desplaza una hoja móvil de ventana (2) con dimensiones aproximadas de 550 × 900 mm, equipada con rueda guía (19) para reducir la fricción,

complementada por una segunda hoja (3) fija.

Asimismo, el sistema incorpora una ventana de ventilación (12) de 300 × 300 mm,

en cuyo interior se monta un motor extractor (20) de 25 W conectado a un segundo

eje (21) que acciona aspas (22) de Ø200 mm. En operación, cuando el sensor

detecta fuga de gas, se activa la luz y la alarma, mientras el servomotor abre la hoja

móvil y el ventilador evacua rápidamente el gas acumulado. Esta combinación de

detección inmediata, aviso sonoro y visual, ventilación automática y extracción

forzada proporciona un entorno mucho más seguro, reduciendo el riesgo de

accidentes domésticos y protegiendo tanto a los habitantes como a la vivienda.

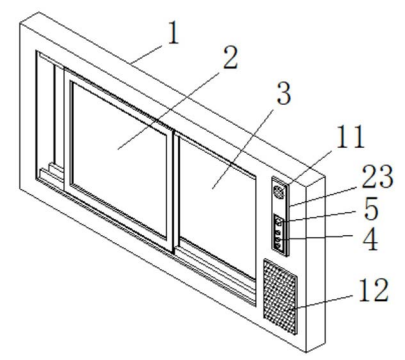
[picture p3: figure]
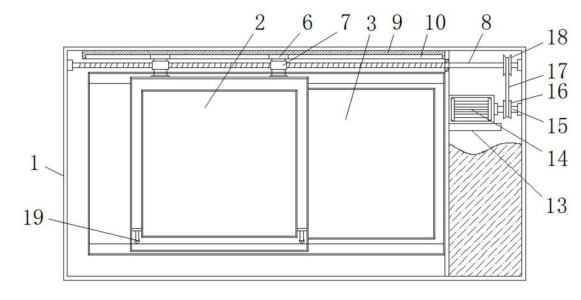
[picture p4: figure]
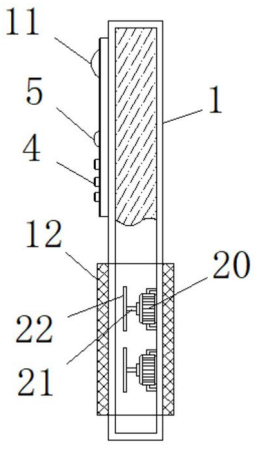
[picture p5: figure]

4.2. Patente 2:
- Nombre de la patente: Dispositivo automático de alarma y apertura de

ventana por fuga de gas natural:

- País de origen: China
- Fecha de patentado: 28 de junio de 2022
- Código: CN216841152U
- Enlace directo:

https://worldwide.espacenet.com/patent/search/family/082107095/publ

ication/CN216841152U?q=CN216841152U (https://worldwide.espacenet.com/patent/search/family/082107095/publication/CN216841152U?q=CN216841152U)

La patente CN 216841152 U, fue solicitada el 6 de diciembre de 2021

(número de solicitud 202123045148.1) y publicada el 28 de junio de 2022 en

China, a nombre del North China Institute of Aerospace Engineering. El

invento pertenece al campo de la ingeniería mecánica y busca dar respuesta al

riesgo de fugas de gas natural en entornos urbanos, que pueden generar

incendios o explosiones si no se controlan de manera rápida y eficiente.

El dispositivo combina un sistema de detección de gases, un módulo de alarma

y un mecanismo de apertura automática de ventanas. Está formado por un

conjunto de ventana con un marco, un tornillo sin fin (husillo) y un motor sin

escobillas que permite mover el vidrio; además, incluye un módulo de control

eléctrico que recibe la señal de los sensores de gas. Cuando el detector

identifica una fuga, se envía la señal al controlador, el cual activa tanto la

alarma sonora como el motor para abrir la ventana de forma inmediata,

permitiendo ventilar el espacio. El sistema cuenta también con un conjunto

hidráulico y deslizante que amplía el rango de detección, haciendo que los sensores se desplacen y cubran un área mayor sin necesidad de colocar

muchos detectores fijos.

En cuanto a sus dimensiones funcionales y básicas, la patente describe los

componentes clave: el marco (4), el husillo roscado (5), el motor (7), el vidrio

móvil (9), el controlador (27), la caja de control eléctrico (8) y los detectores

automáticos (36) con sus alarmas (37). Se incluyen además elementos de

montaje como placas, rieles y deslizadores que permiten un movimiento suave

y seguro. Todo el sistema está diseñado para ser compacto y adaptable a

ventanas de viviendas o espacios cerrados, garantizando que, ante una fuga de

gas, no solo se emita un aviso, sino que también se ejecute la acción de abrir el

vidrio para evacuar rápidamente el gas.

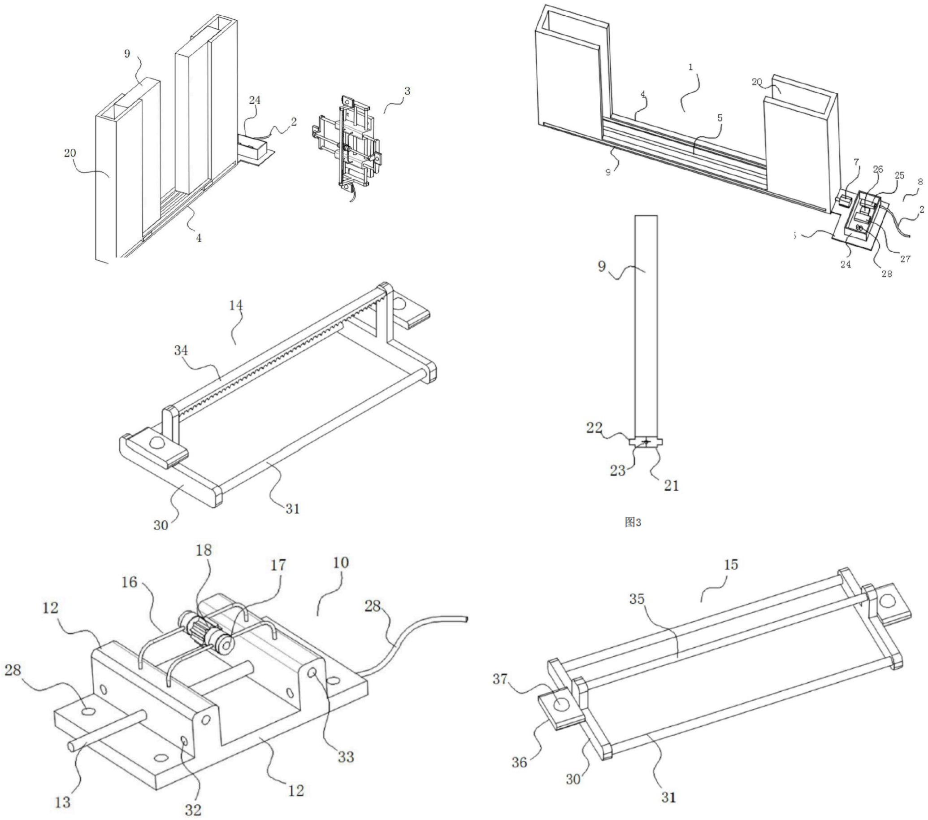
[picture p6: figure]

4.3. Patente 3:

Nombre de la patente: Aparato de apertura automática de ventana tras

detección de fuga de gas

País de origen: China

Fecha de patentado : 16 de octubre de 2020

Código: CN111779409A

Enlace directo:

https://worldwide.espacenet.com/patent/search/family/072763420/publication/CN111

779409A?q=CN111779409A (https://worldwide.espacenet.com/patent/search/family/072763420/publication/CN111779409A?q=CN111779409A)

El presente invento propone un dispositivo diseñado para abrir de manera automática una

ventana cuando se detecta una fuga de gas en el interior de una vivienda. La finalidad de esta

solución es mejorar la seguridad de los hogares, ya que las fugas de gas, provocadas

habitualmente por válvulas abiertas o defectos en la instalación, pueden derivar en

intoxicaciones o incluso explosiones. El sistema integra tanto la capacidad de detección como

la acción mecánica de desbloquear y abrir la ventana, además de ventilar el ambiente para

reducir la concentración de gas.

La estructura principal del dispositivo es una carcasa que se fija directamente sobre la pared y

que contiene en su interior los distintos módulos. En la parte inferior derecha se encuentra el

mecanismo de desbloqueo, compuesto por un motor actuador que hace girar un eje y un

rodillo convexo. Este movimiento se transmite a un panel rotatorio provisto de ranuras y

placas de bloqueo, que interactúan con la manija de la ventana y su pestillo. Al activarse, el sistema consigue liberar la cerradura de la hoja de vidrio, dejando lista la ventana para ser

empujada hacia afuera.

Por encima del módulo de desbloqueo se sitúa el mecanismo de apertura, basado en un motor

telescópico que acciona un bloque deslizante. Dicho bloque está conectado a un conjunto de

palancas y ejes que transmiten la fuerza hasta un cabezal de empuje. Este cabezal actúa

directamente sobre la ventana, desplazándola hacia el exterior de manera controlada. El

diseño aprovecha un sistema de palancas simétricas que aseguran un movimiento firme y

eficiente, permitiendo que la apertura se produzca incluso si la ventana ofrece cierta

resistencia.

En el lateral de la carcasa se incorpora el módulo de detección, compuesto por un sensor de

gas que monitoriza de forma continua la concentración en el aire. Cuando el sensor identifica

niveles peligrosos, activa una alarma sonora y al mismo tiempo pone en marcha el motor de

desbloqueo para liberar la ventana. Una vez liberada, el motor telescópico se encarga de

abrirla y, de manera simultánea, un pequeño ventilador eléctrico con aspas empieza a

funcionar. Este ventilador fuerza la circulación del aire hacia el exterior, facilitando la

evacuación del gas acumulado y reduciendo rápidamente el riesgo para los habitantes.

El sistema está diseñado para funcionar de forma completamente automática: en condiciones

normales permanece inactivo, pero al detectar gas actúa de manera secuencial y coordinada,

primero liberando el cierre, después empujando la ventana y finalmente activando la

ventilación asistida. Con ello, se logra una triple acción de seguridad: detección temprana,

apertura inmediata y extracción del gas. La invención se presenta así como una solución

integral, sencilla de implementar en entornos domésticos, capaz de salvar vidas al reducir los

riesgos derivados de fugas de gas y al garantizar una ventilación rápida y eficaz en

situaciones de emergencia.

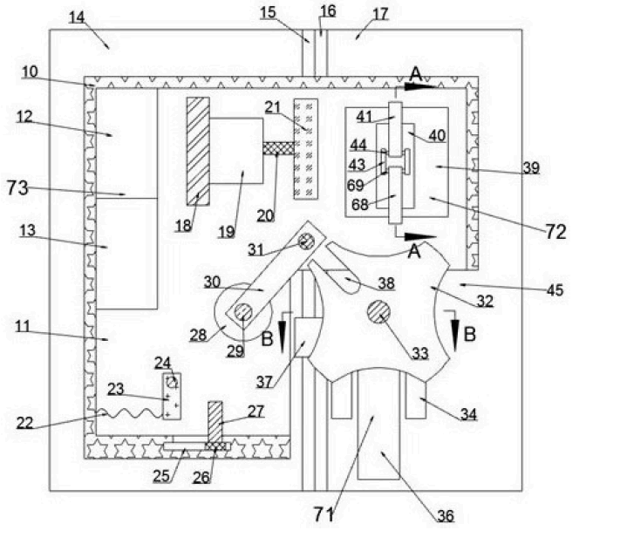
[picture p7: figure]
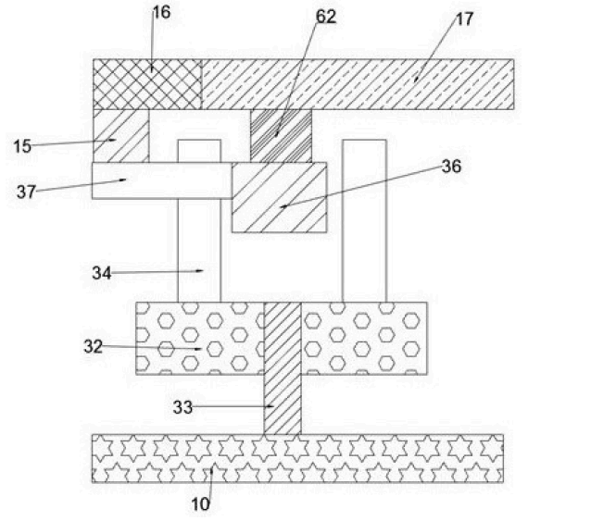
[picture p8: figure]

### 5. Productos comerciales:

### 5.1. Producto 1:

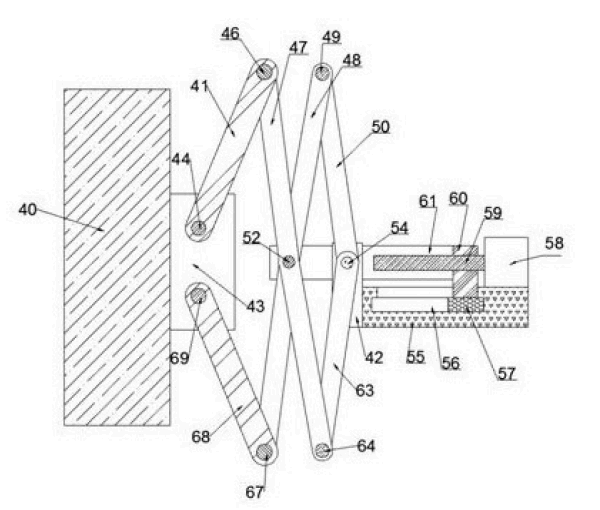
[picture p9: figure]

YFK Sensor Inteligente WiFi para Puertas y Ventanas - Alarma Magnética

Inalámbrica en Tiempo Real, Detector de Seguridad de Pared a Batería para el

Hogar, Seguridad de Mascotas, Alarma de Piscina, Compatible con Alexa y

Google Home, Diseño Elegante, Dispositivo Inteligente para el Hogar,

Accesorio Moderno para el Hogar.

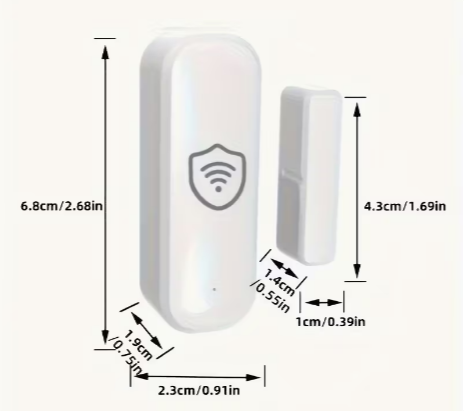
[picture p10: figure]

### 5.2. Fulllink Smart Window Actuator

Fulllink ha desarrollado un actuador motorizado para ventanas que puede

integrarse con sistemas inteligentes para regular la ventilación del ambiente. Al

combinarse con sensores de calidad del aire, temperatura y humedad, el sistema

ajusta la posición de la ventana para mantener condiciones interiores óptimas.

También incorpora mecanismos de seguridad como detección de obstáculos (para

detener el movimiento si algo bloquea la ventana) y modo manual cuando hay

fallas de energía.

Este actuador puede conectarse con sistemas inteligentes del hogar como

Google Home o Apple HomeKit, lo que permite control remoto y

automatización. En cuanto al mercado, no encontré tantas críticas públicas,

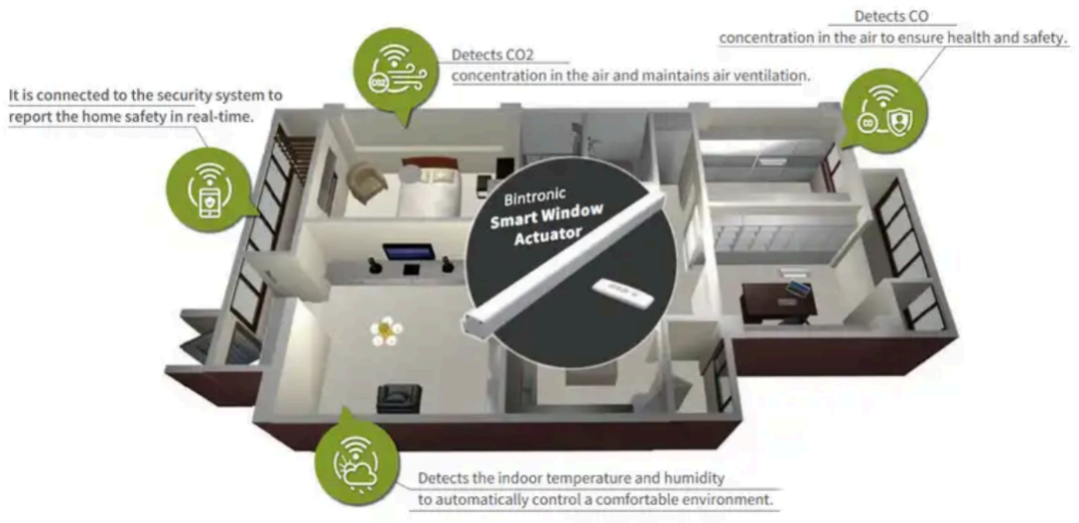
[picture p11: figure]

pero su enfoque en salud (detección de CO, PM2.5) muestra que su propuesta

apunta hacia hogares conscientes de la calidad del aire.

5.3. SMARTWI:

SMARTWI es un dispositivo IoT desarrollado por la empresa Vektiva que

controla la ventilación de ventanas automáticas. Su diseño pretende ser

discreto, silencioso y confiable. Se instala en ventanas tipo tilt-turn, comunes

en Europa, y no requiere perforaciones gracias a cintas 3M en algunos casos.

Funcionalidades principales:

1. Control remoto vía WiFi desde smartphone o PC, mediante interfaz

web.

2. Programación de aperturas y cierres según horarios, porcentaje de

ventilación, acciones automáticas como cerrar cuando llueva,

reaccionar al cambio de temperatura o humedad, e integración con

otros sensores del hogar.

3. Múltiples SMARWI pueden sincronizarse o actuar juntos, incluso

comunicarse por API para integrarse en sistemas más grandes.

4. Ajustes finos (“finetune”) para adaptar parámetros de movimiento,

potencia, velocidad, posiciones límite, sensibilidad ante bloqueo, entre

otros.

Cómo lo toman los usuarios / mercado

1. Vende principalmente en países europeos, con distribución dentro de la

Unión Europea.

2. Usuarios valoran la capacidad de automatizar ventilación diaria,

mejorar la calidad del aire interior y el confort, especialmente en

viviendas con ventanas de difícil acceso.

3. Para usuarios más avanzados, se ha desarrollado integración con

sistemas domóticos (por ejemplo, hay código abierto para integrarse

con Home Assistant).

4. Algunos usuarios podrían sentir limitaciones: no detecta

automáticamente gases tóxicos específicos como CO por sí solo

(depende de sensores externos), y su eficacia depende de la correcta

calibración y ajustes finos.

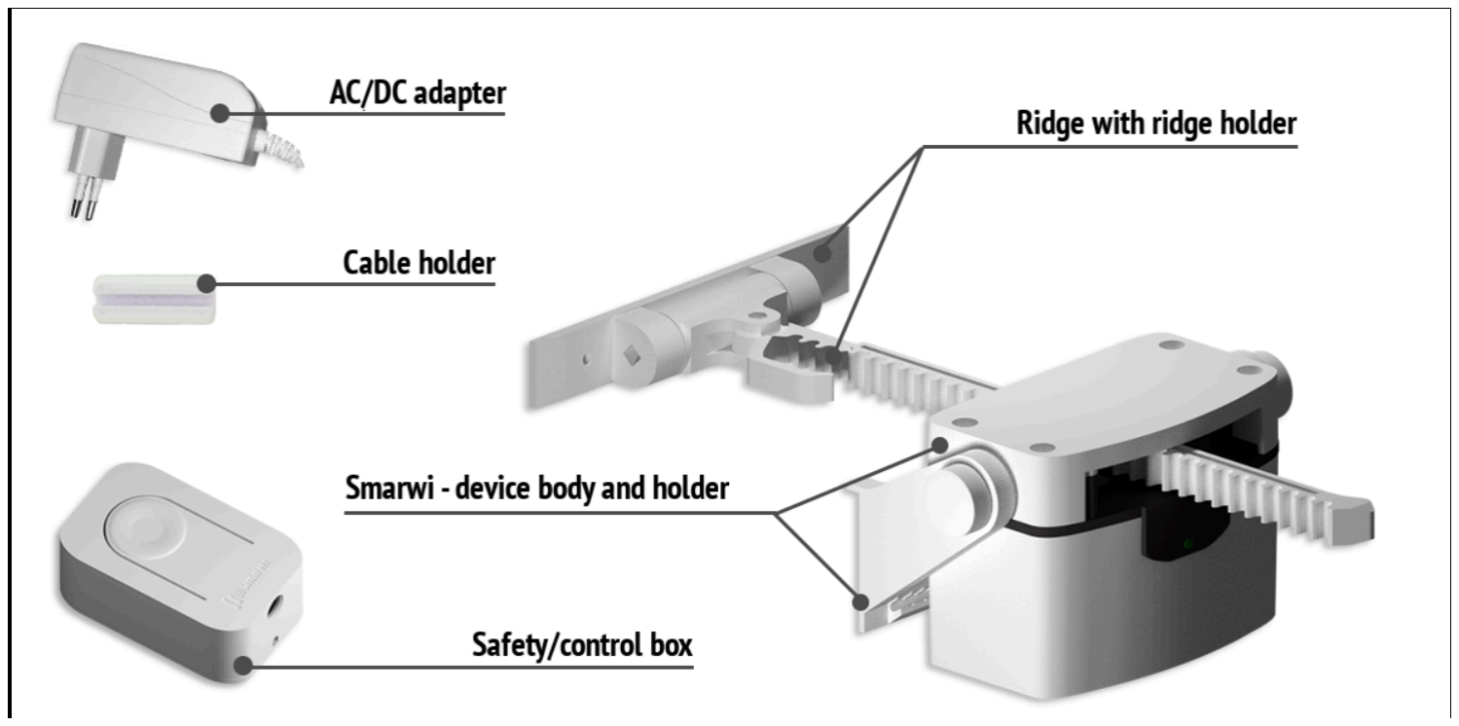
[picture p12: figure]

### 6. Lista de exigencias:

LISTA DE EXIGENCIA

Páginas: 6

Edición:

PROYECTO: | SmartVent

Fecha: 29/09/25

Revisado:

CLIENTE: | UNIVERSIDAD PERUANA CAYETANO HEREDIA | Elaborado: I.P , E.P, S.C, C.Q
Fecha (cambios) | Deseo o Exigencia | Descripción | Responsable
23/09/25 | E | Función principal: ● Integrar sensores de gases y temperatura en ventanas retrofit para accionar la ventilación automática. ● Detectar fugas de gases, cambios bruscos de temperatura y niveles de humedad que puedan afectar la salud y seguridad de los habitantes, y abrirse automáticamente para ventilar el espacio.
| | Función secundaria: ● Enviar alertas locales y remotas en situaciones de emergencia, contribuyendo a la seguridad del entorno. ● Reconocer la calidad del aire exterior y en caso de que esté contaminado, cerrarse automáticamente para evitar que entre al interior.

I.P, E.P, S.C, C.Q

23/09/25 | E | Geometría: El módulo retrofit debe ser compacto y adaptable a marcos existentes, con dimensiones de referencia que permitan una instalación segura sin afectar la ergonomía del usuario ni la compatibilidad con marcos estándar. | E.P, S.C
23/09/25 | E | Cinemática: El mecanismo de apertura y cierre debe garantizar un movimiento estable y seguro de la hoja móvil. Para ello se empleará un sistema motorizado con transmisión mecánica que permita aperturas parciales programadas y apertura total en situaciones de emergencia, | I.P, E.P,

| | manteniendo la integridad estructural de la ventana.
23/09/25 | E | Fuerzas: El actuador debe superar el peso de la hoja y las resistencias externas como fricción y presión del viento, considerando un margen de seguridad adecuado. Además, debe prevenir desalineaciones y contar con mecanismos de detección de obstáculos para asegurar un funcionamiento confiable. | S.C, C.Q
23/09/25 | E | Energía: El sistema debe alimentarse de la red eléctrica convencional, incorporando una fuente de conversión adecuada para el motor, extractor y sensores. Contará con respaldo energético mediante batería recargable y un sistema de apoyo renovable, que asegure autonomía en situaciones de emergencia. Además, debe incluir protecciones eléctricas básicas y gestión en modo reposo para optimizar el consumo. | E.P, S.C
23/09/25 | E | Materia: Flujo material y transporte: Aire interior y exterior (intercambio controlado). Propiedades físicas y químicas: Concentración de CO₂, CO, CH₄, LPG, partículas PM2.5, humedad relativa y temperatura. Productos de entrada y salida: Entrada de aire limpio; salida de aire contaminado o con gases tóxicos. Materiales adicionales: Marcos anticorrosivos, vidrio, motores, sensores. Materiales prescritos (normativa): Cumplimiento de normas de seguridad contra incendios y calidad del aire (referencia a OMS e INDECI). | I.P, E.P, S.C, C.Q
23/09/25 | E | Señales (información): El sistema deberá contar con las siguientes señales de entrada y salida: Señales de entrada: ● Señal de encendido: Sirve para energizar los componentes eléctricos y electrónicos que conforman la máquina. ● Señal de inicio: Esta señal pone en marcha el funcionamiento conjunto del proceso. ● Señal de parada: Permite detener el proceso en cualquier etapa de su funcionamiento.

- Señales de sensores:
Lecturas de sensores ambientales
- Sensor de gases
- Sensor de partículas en suspensión,
- Sensor de temperatura y humedad. Señales de salida:
- Señal de Stand-by: Permite conocer si los sensores y actuadores se encuentran listos para trabajar luego de energizarse.
- Señales de estado: Informan al operario sobre el estado actual de sensores y actuadores (ventana abierta/cerrada, extractor activo/inactivo).
- Señal de emergencia: En caso de presentarse una situación que comprometa el proceso o la seguridad, se emitirá una señal que activará alarmas sonoras, visuales y notificaciones remotas.
- Señal de fin de proceso: Indica al operario la finalización de un ciclo de ventilación o del procedimiento ejecutado.
- Señales de control a actuadores: Instrucciones de apertura/cierre de la ventana, activación del extractor o activación de alarmas según lo determine el algoritmo de control.

I.P, E.P, S.C, C.Q

23/09/25 | E | Control: El sistema de SmartVent supervisa constantemente las condiciones del aire dentro del hogar. ● Un algoritmo procesa la información de los sensores y decide si abrir, cerrar, accionar el extractor o enviar una alerta. ● Ópera en tres modos: normal, ventilación parcial y emergencia. ● Garantiza supervisión en tiempo real con retroalimentación inmediata hacia los aparatos de los usuarios. | I.P, E.P,
23/09/25 | E | Electrónico (Hardware): SmartVent está equipado con todo lo necesario para funcionar de manera confiable y continua: ● Centro: un pequeño “programa autónomo” que coordina todo el sistema y decide qué hacer en cada

| | situación. ● Sensores inteligentes: detectan la presencia de gases, el nivel de partículas, la temperatura y la humedad en el ambiente. ● Mecanismos de acción: permiten que la ventana se abra, se cierre o que se encienda un extractor para renovar el aire. ● Energía asegurada: funciona conectado a la corriente eléctrica, pero además cuenta con batería de respaldo y la opción de usar energía solar para no depender siempre de la red. | S.C, C.Q
23/09/25 | E | Software: El sistema ofrece interfaces modernas y accesibles: ● Aplicación móvil con gráficos claros, alertas y control manual y de fácil manipulación. ● Dashboard con indicadores en tiempo real e historial de calidad de aire del espacio circundante. ● Firmware especializado en adquisición de datos y control preciso de los actuadores. ● Notificaciones automáticas vía IoT ( SMS o email). | S.C, E.P
23/09/25 | E | Comunicaciones: SmartVent garantiza una conexión estable y segura en todo momento. El sistema se comunica de manera inalámbrica y confiable, lo que permite que el usuario reciba alertas inmediatas sobre lo que ocurre dentro de su hogar. Esta comunicación es de doble sentido: no solo informa lo que está pasando, sino que también da la posibilidad de actuar a distancia, por ejemplo, cerrar la ventana desde el móvil aunque uno no esté en casa. | I.P
23/09/25 | E | Seguridad: La prioridad número uno de SmartVent es proteger a las personas. El sistema es capaz de detectar humo, gases y partículas peligrosas en el ambiente y, de manera automática, responde abriendo la ventana para expulsar el aire y emitiendo alarmas sonoras y visuales para alertar a los ocupantes. Incluso en caso de un corte de electricidad, la ventana seguirá operativa gracias a su batería de respaldo y siempre se podrá accionar manualmente si es necesario. | I.P, E. P.

23/09/25 | E | Ergonomía: SmartVent ha sido diseñado pensando en todos los usuarios, desde niños hasta adultos mayores. Su funcionamiento es suave, silencioso y sin esfuerzo, garantizando una apertura y cierre que no interrumpe la vida cotidiana. La aplicación móvil cuenta con una interfaz clara e intuitiva, lo que facilita el uso incluso para personas con movilidad reducida o poca experiencia con la tecnología. | S.C , C.Q
23/09/25 | E | Fabricación: La construcción del sistema se ha planteado con criterios de durabilidad y sostenibilidad. Se emplean materiales resistentes a la humedad y la corrosión, asegurando que el producto soporte ambientes urbanos exigentes. Además, su diseño modular facilita la sustitución de piezas cuando sea necesario, lo que alarga la vida útil del producto. La producción combina talleres locales para las partes estructurales con proveedores externos para los componentes electrónicos, garantizando un equilibrio entre calidad y disponibilidad. | E. P, I.P, S.C, C.Q
23/09/25 | E | Control de calidad: Antes de ser instaladas, todas las unidades de SmartVent pasarán por un riguroso proceso de pruebas. Los sensores son expuestos a distintos niveles de gases y partículas para comprobar su precisión. Los mecanismos de apertura y cierre se probarán en diferentes condiciones para verificar que siempre funcionen con seguridad. Finalmente, se realizará pruebas en entornos reales, como viviendas o centros educativos, para asegurar que la respuesta del sistema sea eficaz en situaciones concretas. | I.P, E.P
23/09/25 | E | Montaje: La instalación de SmartVent es rápida y versátil, ya que se adapta a marcos de ventanas existentes o puede instalarse en ventanas nuevas, guiándose de un manual intuitivo que facilita el proceso y a un manual claro que guía todo el proceso. | S.C, C.Q
23/09/25 | E | Transporte: Pensando en su distribución, SmartVent es ligero y compacto, con un peso que no debe superar los 2,5 kg. Cada unidad se embala con materiales de protección contra golpes, humedad y polvo, lo que facilita su transporte tanto de forma manual como en vehículos convencionales. | E.P

23/09/25 | D | Uso: El sistema está concebido para la vida cotidiana en distintos entornos, ya sean viviendas, oficinas o colegios. Su funcionamiento silencioso y ergonómico asegura comodidad y tranquilidad. Además, en caso de emergencia, siempre se cuenta con la opción de desbloqueo manual. | I.P
23/09/25 | E | Mantenimiento: SmartVent apenas requiere cuidados. Con una limpieza de los sensores y una revisión de la batería cada seis meses es suficiente para asegurar su buen rendimiento. Además, el sistema es capaz de realizar diagnósticos automáticos y avisar al usuario si detecta alguna falla que requiera atención. | S.C, E.P
23/09/25 | E | Costos: Se ha pensado en que el producto sea competitivo y accesible. Utiliza componentes de fácil adquisición, lo que permite mantener bajos los costos de producción y facilitar el reemplazo de piezas. La inversión se amortiza en un periodo estimado de dos a tres años gracias a la durabilidad y bajo consumo del sistema. | I.P, E.P
23/09/25 | E | Plazos: El desarrollo de SmartVent es ágil y realista. Desde el diseño inicial hasta las primeras pruebas de prototipo y la producción piloto, se estima un periodo de dos a tres meses. | C.Q, I.P

### 7. Plan de trabajo:

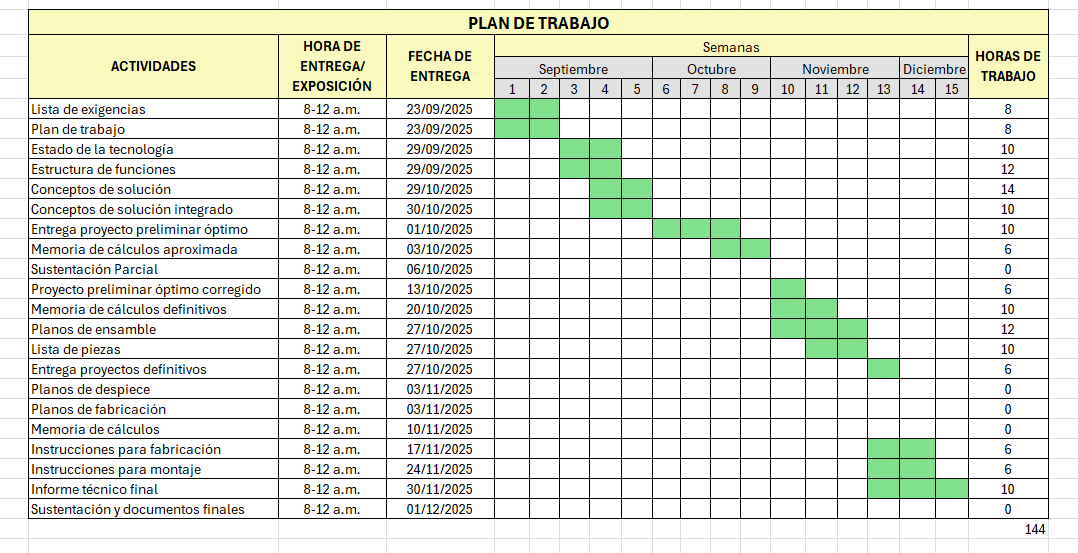
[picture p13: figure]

Referencia Bibliografía:

### 1. Artículos relacionados:

- Babu, T., Nair, R. R., Kishore, S., & Vineeth, M. (2024). Enhancing gas leak

detection with IoT technology: An innovative approach. Procedia Computer

Science, 235, 961–969. https://doi.org/10.1016/j.procs.2024.04.091

- Garcia, A., Saez, Y., Harris, I., Huang, X., & Collado, E. (2025).

Advancements in air quality monitoring: A systematic review of IoT-based air

quality monitoring and AI technologies. Artificial Intelligence Review, *58*,

275. https://doi.org/10.1007/s10462-025-11277-9
- Shah, A. S., Dinesh, A., Shah, A., Farooq, M., Maqsood, A., & Khani, M.
A. K. (2024). Smart Gas Leak Detection And Emergency Response System

Using IoT For Homes. Journal of ICT, Design, Engineering and Technological

Science, 8(1), 18–23. https://doi.org/10.33150/JITDETS-8.1.3

- Benammar, M., Abdaoui, A., Ahmad, S. H. M., Touati, F., & Kadri, A. (2018).

A modular IoT platform for real-time indoor air quality monitoring. Sensors,

18(2), 581. https://doi.org/10.3390/s18020581

2. Patentes relacionados:
- Huang, Z., Chen, Y., & Li, J. (2020). Un sistema de monitoreo de calidad del

aire interior (Patente No. CN212201795U). Administración Nacional de

Propiedad Intelectual de la República Popular China.

https://worldwide.espacenet.com/patent/search/family/073692329/publication/

CN212201795U?q=CN212201795U (https://worldwide.espacenet.com/patent/search/family/073692329/publication/CN212201795U?q=CN212201795U)

- Zhou, J., Liu, Y., Wang, X., & Li, S. (2022). Un dispositivo de monitoreo de

calidad del aire para interiores (Patente No. CN216841152U). Administración

Nacional de Propiedad Intelectual de la República Popular China.

https://worldwide.espacenet.com/patent/search/family/082107095/publication/

CN216841152U?q=CN216841152U (https://worldwide.espacenet.com/patent/search/family/082107095/publication/CN216841152U?q=CN216841152U)

- Kane, D. P., & Dumas, B. P. (2012). Sistema y método de seguridad para

ventanas (Patente No. WO2013015592A2). Organización Mundial de la

Propiedad Intelectual.

https://worldwide.espacenet.com/patent/search/family/047601640/publication/

WO2013015592A2?q=security%20windows%20for%20crime (https://worldwide.espacenet.com/patent/search/family/047601640/publication/WO2013015592A2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)

3. Productos comerciales:

link:
https://www.temu.com/us-es/kit-de-alarma---puertas-y---de-yfk-paq uete-de-2-montaje-en---de-seguridad---controlado-por-aplicacion--con-pilas-aa--con--y-google-----la-habitacion-de---g-601099625814 709.html?refer_page_name=goods&refer_page_id=10032_175877 6719635_6gwldrqyjz&refer_page_sn=10032&_x_sessn_id=eicupfn qcp (https://www.temu.com/us-es/kit-de-alarma---puertas-y---de-yfk-paquete-de-2-montaje-en---de-seguridad---controlado-por-aplicacion--con-pilas-aa--con--y-google-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)

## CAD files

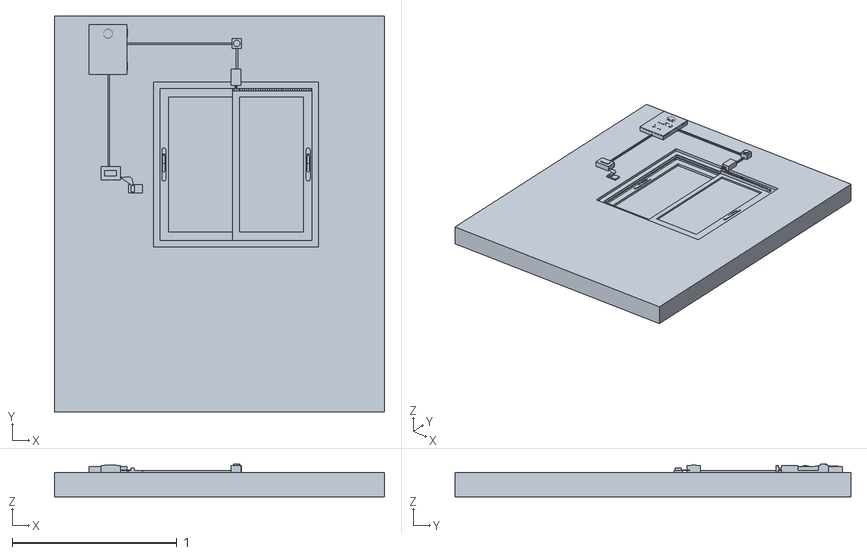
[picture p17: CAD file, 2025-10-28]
FundDiseño/Presentaciones de Proyecto/MODELO 1.obj
2.00 x 2.40 x 0.2

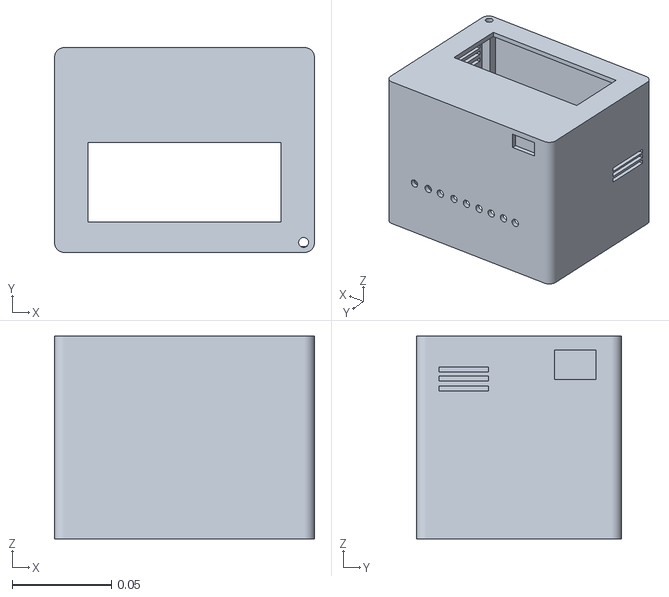
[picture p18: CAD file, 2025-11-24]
Proyecto/MóduloMecánico/Caja.stl
0.131 x 0.103 x 0.102

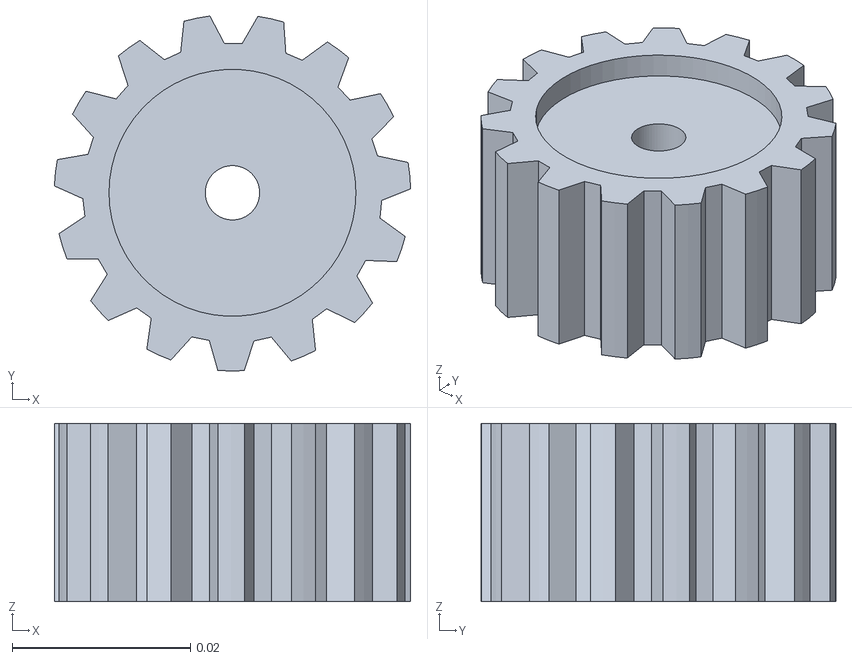
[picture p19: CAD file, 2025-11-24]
Proyecto/MóduloMecánico/Engranaje.stl
0.04 x 0.0398 x 0.02

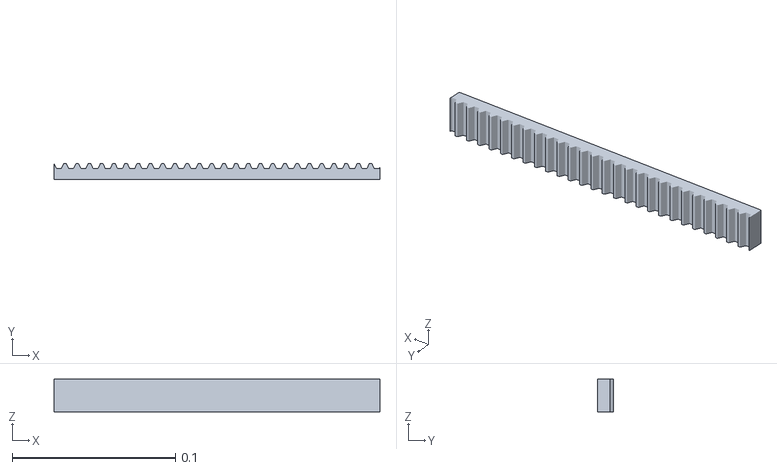
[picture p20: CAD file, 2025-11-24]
Proyecto/MóduloMecánico/Correa de ventana.stl
0.2 x 0.01 x 0.02

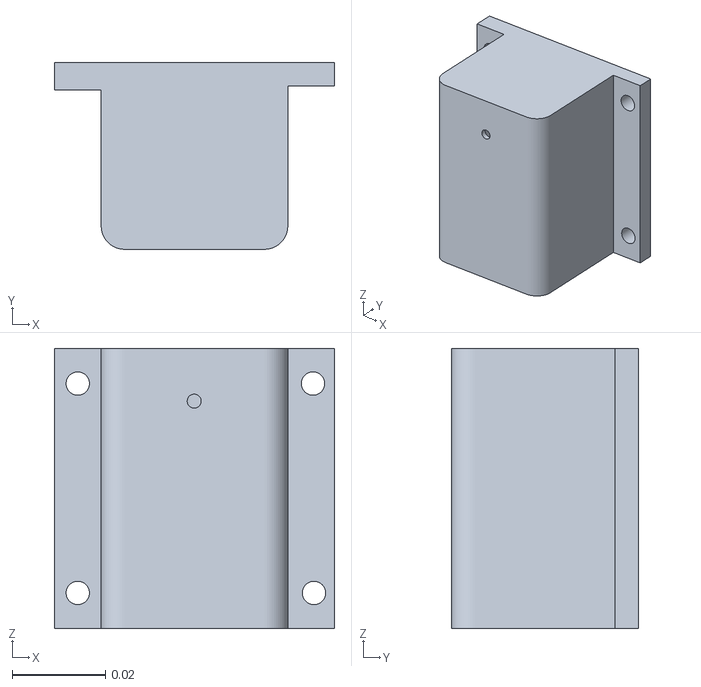
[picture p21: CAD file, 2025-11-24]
Proyecto/MóduloMecánico/Soporte del motor.stl
0.06 x 0.04 x 0.06

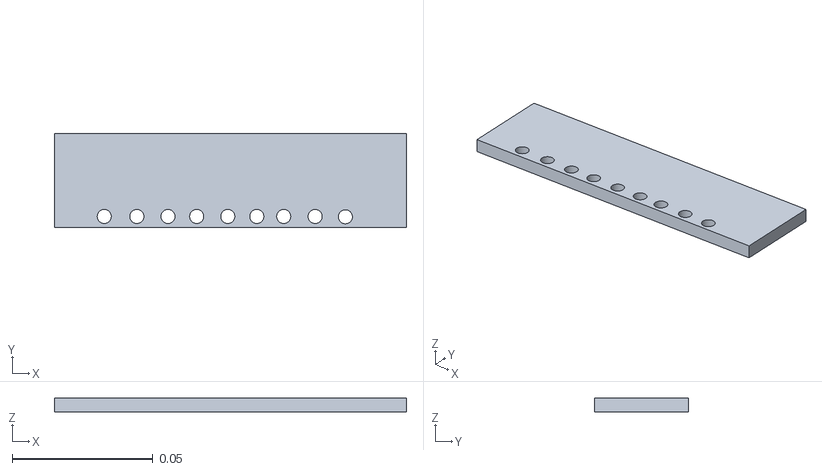
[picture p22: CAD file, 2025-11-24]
Proyecto/MóduloMecánico/soporte.stl
0.125 x 0.0335 x 0.005

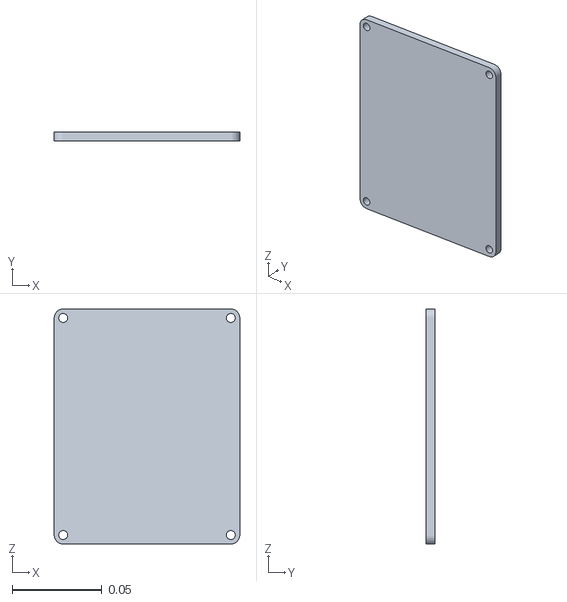
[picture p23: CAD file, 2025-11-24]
Proyecto/MóduloMecánico/tapa.stl
0.103 x 0.005 x 0.131

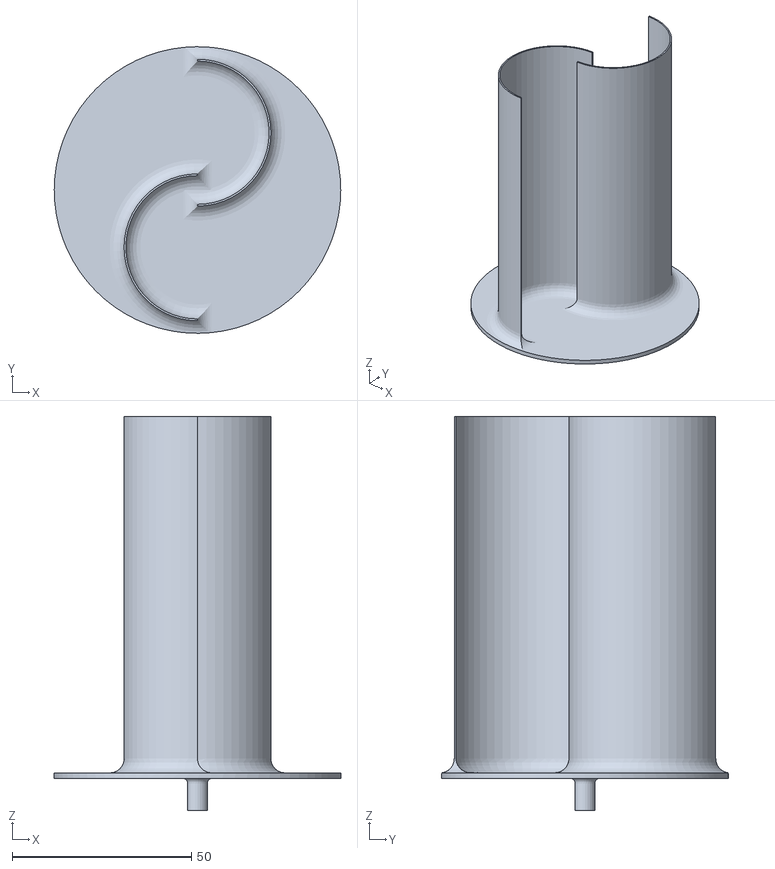
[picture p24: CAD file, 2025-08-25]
Proyecto/MóduloMecánico/WeatherStation_v2_windmill_v4.stl
80.0 x 80.0 x 110.0

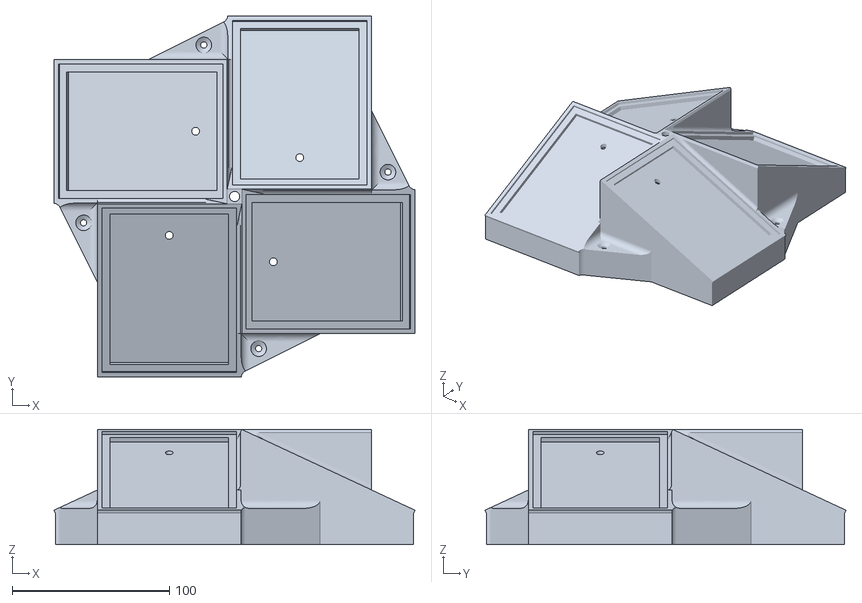
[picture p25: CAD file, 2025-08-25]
Proyecto/MóduloMecánico/WeatherStation_v2_Base_v2.stl
229.5 x 229.5 x 73.2

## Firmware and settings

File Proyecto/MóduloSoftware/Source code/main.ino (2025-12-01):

#include <Wire.h> 
#include <Adafruit_Sensor.h>
#include <Adafruit_BME280.h>
#include <LiquidCrystal_I2C.h>
#include <WiFi.h>
#include <ESPAsyncWebServer.h>

// Pines motor (UN SOLO GIRO)
const int IN1 = 32;   // dirección fija
const int ENA = 25;   // habilitar motor

// LEDs y buzzer
const int LED_ROJO = 4;
const int LED_VERDE = 2;
const int BUZZER = 13;

// Sensores
const int MQ2_PIN = 34;        
const int SENSOR_CORRIENTE = 33;

// Umbrales
const int MQ2_UMBRAL = 250;
const float TEMP_UMBRAL = 35.0;
const float STALL_A = 9.0; // Amperios para declarar atasco

// Filtrado / detección
const int MED_N = 7;
const int AVG_N = 5;
const float IIR_ALPHA = 0.3f;
const int REQUIRED_CONSEC = 7;
const int SAMPLE_MS = 150;

// Retraso inicial
int totalSeg = 90;

// BME280 + LCD
Adafruit_BME280 bme;
LiquidCrystal_I2C lcd(0x27, 20, 4);

// Buffers filtrado
int medBuf[MED_N];
int medIdx = 0;
bool medFull = false;
float avgBuf[AVG_N];
int avgIdx = 0;
bool avgFull = false;
float iirValue = 0.0f;

int consecHigh = 0;
bool motor_atascado = false;
bool app_conectada = false;

// WiFi
const char* ssid = "UPCH_CENTRAL";
const char* password = "CAYETANO2022";

// Servidor web
AsyncWebServer server(80);


// --------------------------------------------------------------------
void setup() {
  Serial.begin(115200);

  // Pines motor
  pinMode(IN1, OUTPUT);
  pinMode(ENA, OUTPUT);

  // LEDs y buzzer
  pinMode(LED_ROJO, OUTPUT);
  pinMode(LED_VERDE, OUTPUT);
  pinMode(BUZZER, OUTPUT);

  // Sensores
  pinMode(MQ2_PIN, INPUT);
  pinMode(SENSOR_CORRIENTE, INPUT);

  // BME280
  if (!bme.begin(0x76)) {
    Serial.println("No se encontró BME280");
    while (1);
  }

  // LCD
  lcd.init();
  lcd.backlight();

  // WiFi
  WiFi.begin(ssid, password);
  lcd.setCursor(0,0);
  lcd.print("Conectando WiFi...");
  while (WiFi.status() != WL_CONNECTED) {
    delay(500);
    lcd.print(".");
  }

  lcd.clear();
  IPAddress ip = WiFi.localIP();

  // Timer de inicio (SE QUEDA)
  for (int i = totalSeg; i >= 0; i--) {
    lcd.setCursor(0,0);
    lcd.print("SmartVent :)      ");
    lcd.setCursor(0,1);
    lcd.print("IP: "); lcd.print(ip);
    lcd.setCursor(0,2);
    lcd.print("Iniciando en: ");
    lcd.print(i); lcd.print("s  ");

    delay(1000);
  }
  lcd.clear();

  // Inicial IIR
  iirValue = analogRead(SENSOR_CORRIENTE);

  // API
  server.on("/api/ultimo", HTTP_GET, [](AsyncWebServerRequest *request){
    bool alerta = (analogRead(MQ2_PIN) >= MQ2_UMBRAL ||
                   bme.readTemperature() >= TEMP_UMBRAL);

    String json = "{";
    json += "\"temperatura\":" + String(bme.readTemperature(),1) + ",";
    json += "\"mq2\":" + String(analogRead(MQ2_PIN)) + ",";
    json += "\"alerta\":" + String(alerta ? "true" : "false") + ",";
    json += "\"atascado\":" + String(motor_atascado ? "true" : "false");
    json += "}";

    request->send(200, "application/json", json);
    app_conectada = true;
  });

  server.begin();
}


// --------------------------------------------------------------------
void loop() {
  float temp = bme.readTemperature();
  int mq2 = analogRead(MQ2_PIN);
  float currentA = readFilteredCurrentA();

  bool alerta = (mq2 >= MQ2_UMBRAL || temp >= TEMP_UMBRAL);

  // LED rojo + buzzer (independiente del motor)
  if (alerta) {
    digitalWrite(LED_ROJO, HIGH);
    digitalWrite(BUZZER, HIGH);
  } else {
    digitalWrite(LED_ROJO, LOW);
    digitalWrite(BUZZER, LOW);
  }

  // Motor solo si hay alerta
  if (alerta && !motor_atascado) startMotor();
  else stopMotor();

  // Detección de atasco
  if (digitalRead(ENA) == HIGH) {
    if (currentA >= STALL_A) consecHigh++;
    else if (consecHigh > 0) consecHigh--;

    if (consecHigh >= REQUIRED_CONSEC) {
      motor_atascado = true;
      stopMotor();

      // Beep especial
      for (int i = 0; i < 3; i++) {
        digitalWrite(BUZZER, HIGH); delay(150);
        digitalWrite(BUZZER, LOW); delay(150);
      }
    }
  } else {
    consecHigh = 0;
  }

  // LED verde = normal
  digitalWrite(LED_VERDE, alerta ? LOW : HIGH);

  // LCD
  lcd.setCursor(0,0);
  lcd.print("SmartVent :)       ");

  lcd.setCursor(0,1);
  lcd.print("Temp: "); lcd.print(temp,1); lcd.print(" C   ");

  lcd.setCursor(0,2);
  lcd.print("MQ2: "); lcd.print(mq2); lcd.print("     ");

  lcd.setCursor(0,3);
  if (alerta) {
  lcd.print("ALARMA ACTIVA     ");
  } else {
  lcd.print("Todo normal       ");
}

delay(SAMPLE_MS);
}




// ---------------- Funciones ----------------
float adcToAmps_fromADCavg(float adc_avg) {
  const float ADC_REF = 3.3;
  const int ADC_MAX = 4095;

  float volts = adc_avg * (ADC_REF / ADC_MAX);
  float amps = fabs((volts - 1.65) / 0.100); // ACS712 20A = 100 mV/A
  return amps;
}

int medianOfBuf() {
  int len = medFull ? MED_N : medIdx;
  if (len == 0) return 0;

  int tmp[len];
  for (int i=0; i<len; i++) tmp[i] = medBuf[i];

  for (int i=0; i<len-1; i++)
    for (int j=i+1; j<len; j++)
      if (tmp[i] > tmp[j]) {
        int t = tmp[i];
        tmp[i] = tmp[j];
        tmp[j] = t;
      }

  return tmp[len/2];
}

float avgOfBuf() {
  int len = avgFull ? AVG_N : avgIdx;
  if (len == 0) return 0;

  float s = 0;
  for (int i=0; i<len; i++) s += avgBuf[i];

  return s / len;
}

float readFilteredCurrentA() {
  int raw = analogRead(SENSOR_CORRIENTE);

  medBuf[medIdx] = raw;
  medIdx = (medIdx+1) % MED_N;
  if (medIdx == 0) medFull = true;

  int med = medianOfBuf();

  avgBuf[avgIdx] = med;
  avgIdx = (avgIdx+1) % AVG_N;
  if (avgIdx == 0) avgFull = true;

  float adc_avg = avgOfBuf();

  iirValue = IIR_ALPHA * adc_avg + (1 - IIR_ALPHA) * iirValue;

  return adcToAmps_fromADCavg(iirValue);
}

void startMotor() {
  digitalWrite(IN1, HIGH);
  digitalWrite(ENA, HIGH);
}

void stopMotor() {
  digitalWrite(IN1, LOW);
  digitalWrite(ENA, LOW);
}

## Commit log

2025-11-13 ESQUEMA DE CIRCUITOS Y PCB
2025-11-13 Update ESQUEMA DE CIRCUITOS Y PCB
2025-11-24 Estructura de funciones.md

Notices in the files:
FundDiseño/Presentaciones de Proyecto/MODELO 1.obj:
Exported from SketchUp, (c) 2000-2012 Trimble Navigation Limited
